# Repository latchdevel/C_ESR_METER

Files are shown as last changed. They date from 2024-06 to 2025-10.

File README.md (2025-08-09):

# C/ESR Meter

Capacitance "**C**" and equivalent series resistance "**ESR**" meter for electrolytic capacitors.

Hardware and software reimplementation of the Russian capacitance and ESR meter for electrolytic capacitors, posted on ["Pro-Radio" forum](https://pro-radio.online/measure/3288/) in 2006 by Gints Oleg (Гинц Олег) "GO". As he himself explains on [this website](http://www.rlc-esr.ru/index.php/ru/izmeritel-s-i-esr), he was inspired by a [previous project from 2004](Project_2004), about which there is not much information. Original Gints Oleg design is for sale as "DIY kit" on the ["Modul-X website."](http://modul-x.ru/radiokonstruktory/pribory/izmeritel-emkosti-i-posledovatelnogo-ekvivalentnogo-soprotivleniya-elektroliticheskikh-kondensatorov-c-esr-meter.htm)

In 2021 the user "**wegi1**" from the "Open Source Hardware Lab" forum publishes two projects that include the schematic and the PCB in "EasyEDA", [two dual Op-Amps](https://oshwlab.com/wegi1/oleg-c-esr-meter) and [one quad Op-Amp](https://oshwlab.com/wegi1/go-esr-c-meter)

In 2022 the Spanish Youtube channel "**RDT**" [Reparando de todo](https://www.youtube.com/watch?v=-c8M0YjmY34&list=PLTIVqAL9EezMypRtiyRqnYZjx48QQSnEL) make and share own SMD designs from original based. 

This device is not a precision instrument, but it is sufficient for the practice of radio amateurs and electronic repairs.

It is published under **Open Hardware** and **Open Source** licenses:
   - [CERN Open Hardware Licence Version 2 - Strongly Reciprocal](https://ohwr.org/cern_ohl_s_v2.txt)
   - [GNU General Public License v3.0](https://www.gnu.org/licenses/gpl-3.0.txt)
   - [Creative Commons Attribution-ShareAlike 4.0 International Public License](https://creativecommons.org/licenses/by-sa/4.0/legalcode.txt)

  

## Main features
- Measures ESR from 0.001Ω to 15.00Ω (approx), in two ranges.
- Measures capacitance from 1uF to 100,000uF (approx) very quickly.
- Its electronics are very simple, easy and cheap to build.
- Works below 100 mV on the capacitor under test, allowing in-circuit measurements.
- No capacitor pre-discharge required.
- Calibration by software.

## Principle of measurement
Measuring the capacitor's ESR is based on subjecting it to a pulse from a known current source and measuring the voltage drop across it.

The capacitor will be connected to a known constant current source "I=10mA" for a precise short period of time "10μS", when the capacitor is disconnected from the current source, the voltage across it will decrease as a function of "I*R". Knowing the current and voltage drop, the ESR can be calculated. It should be noted that this principle of measuring ESR is not new, it is simply not very common.

The capacitance is calculated by measuring the charging time of the capacitor between 30mV and 60mV with the same constant current of 10mA. In practice, the "33" gain output is used to compare it with 1V and 2V references.
This time is relatively small, approximately 3 microseconds per microfarad, but can be measured with sufficient precision for the most common capacitances of electrolytic capacitors.

## Reimplementation motivation
I learned about the GO meter thanks to "**RDT**" [Reparando de todo](https://www.youtube.com/watch?v=kafeiWaOLkQ) YouTube channel, which did a great job spreading the word about it.
And I immediately wanted to build one, but I also wanted to be able to modify it to my liking, and the fact that the code was written in assembler language posed a considerable difficulty. Furthermore, the language used was Microchip Assembler (MPASM), which is deprecated in favor of MPLAB XC8 PIC Assembler (pic-as). The last version that includes MPASM was [MPLAB X IDE v5.35 (2020)](https://ww1.microchip.com/downloads/en/DeviceDoc/MPASM%20to%20MPLAB%20XC8%20PIC%20Assembler%20Migration%20Guide%2050002973A.pdf).

Therefore, it made no sense to maintain or rewrite the code in assembler language, and I chose to reimplement it in a more comfortable language like C/C++. So it was no longer necessary to continue using a Microchip PIC, being able to use an Atmel AVR like those used by Arduino ecosystem, having numerous development boards and abundant open software libraries and tools.

This reimplementation of the software and hardware has been possible thanks to the fact that both the scheme and the source code were published, which could be compiled and executed in a simulator, which allowed obtaining a [basic flowchart of the GO meter operation](Russian_source/go_esr_flowchart.png).

Modifying the hardware allows you to add several improvements, some of them absolutely essential:

### VREF Voltage Reference 4 volts
An absolutely essential improvement is to add a 4V voltage reference to use as the VREF of the ADC, from which the 2v and 1v voltages, used as comparator inputs, would also be derived using simple voltage dividers.

Using Vcc (approximately 5V) as the ADC reference voltage is a very bad idea, since this voltage is highly variable and unstable, and it can never be reached at the output of the Op-Amps (if these do not have Rail-to-Rail output), losing measurement range.

The most accurate option would be to use a voltage reference of 4096mV, such as the LM4040 or MCP1541, which are inexpensive and even available in their manufacturers' sample programs, but the simplest thing would be to use another TL431 since it is easily configurable to 4v with only two resistors of 12kΩ and 20kΩ.

$V_o=2.5v*(1+\frac{R1}{R2})=2.5v*(1+\frac{12000Ω}{20000Ω})=2.5v*(1+0.6)=2.5v*1.6=4v$

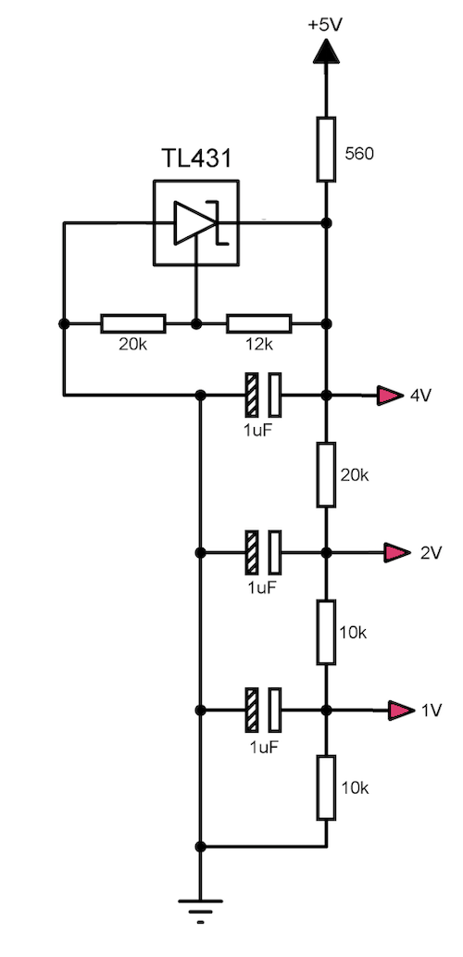
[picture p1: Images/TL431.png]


### AD620 Instrumentation amplifier
Another important improvement is replacing the four operational amplifiers (two TL072 dual Op-Amps or one TL084 quad Op-Amp) with a single AD620 instrumentation amplifier whose gain is configurable, being set by default to "33" and using one of the four switches on the CD4066B that was not used, the "330" gain can be selected.

The AD620 formula to calculate the resistances $R_g$ is:

$G=\frac{49.4kΩ}{R_g}+1$ 

$R_g=\frac{49.4kΩ}{G-1}$

Therefore:
 - For $G$ = 33, $R_g$ = 1543.75Ω approx **1.5kΩ** --> Single resistor (R1)
 - For $G$ = 330, $R_g$ = 150.15Ω approx **150Ω** --> 167Ω parallel circuit 1500Ω --> 143Ω (CD4066B $R_{on}$ @5v)<sup>1</sup> + 24Ω (R2)

 <sup>1</sup> CD4066B Quad bilateral analog switch $R_{on}$ @5v must be measured between pins 8 and 9.

VSS (-5V) negative voltage is still necessary, because it operates very close to zero voltage. Even modern Rail-to-Rail Op-Amps do not achieve an acceptable lineal result when operating so close to zero volts.
But now, the VSS level is not critical, it does not require lineal regulator or manual offset adjustment, since the AD620 has a reference terminal to set the potential that defines the zero output voltage, which can be connected directly to GND.

#### Original circuit with four generics Op-Amps 
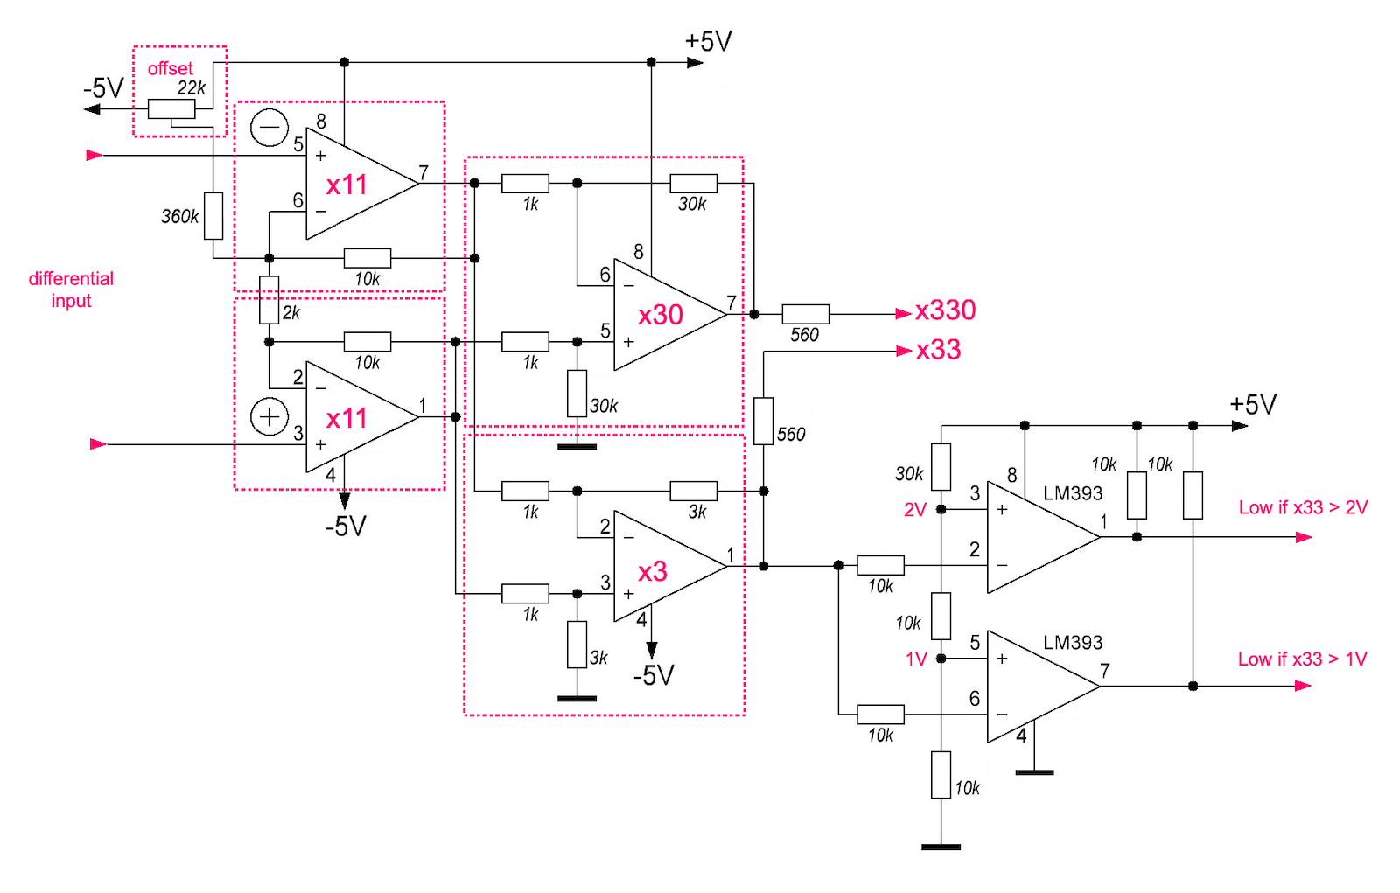
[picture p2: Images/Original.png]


#### New circuit with one instrumentation amplifier AD620
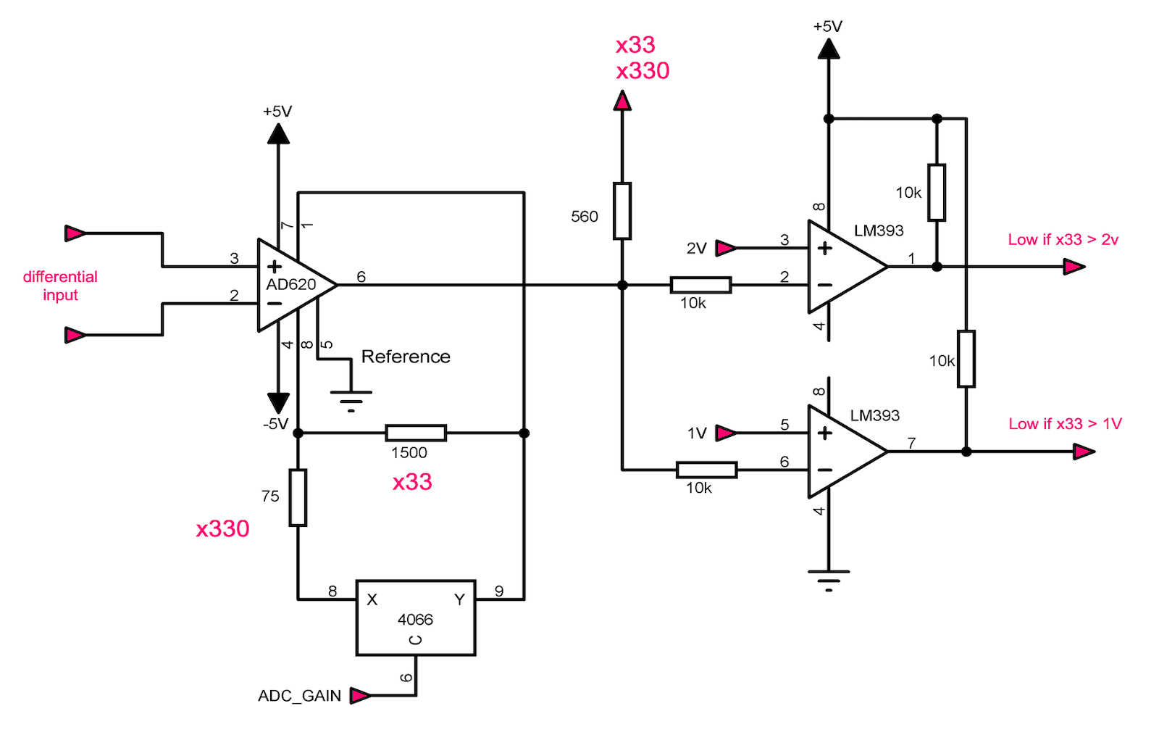
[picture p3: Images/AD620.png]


### MCU ATMega328p "Arduino Nano"
The microcontroller update is another substantial improvement, not only due to the increase in the capacity of program memory and RAM, since when using the Arduino framework there are low-cost development boards, which include all the necessary components and many accessories, from quartz crystal and capacitors, to voltage regulators and USB to Serial converters.
They also include a bootloader that makes it very easy to update firmware using a simple USB connection, without the need for an external hardware programmer.

* Change MCU from Microchip PIC16F87xA to Atmel ATMega328p (Arduino Nano (USB to Serial bridge included))
* Change programming language from old Microchip Assembler (MPASM) to modern C++ standard (avr-gcc c++11)
* Change float resolution from Microchip's 24-bit to IEEE-754 32-bit standard. [See the AN575 Python module for conversions.](https://github.com/latchdevel/AN575)
* Change the external ICSP hardware programmer to built-in USB bootloader for easy firmware update via USB connection.

| MCU | SRAM (bytes) | Program Memory (KB)| Data EEPROM (bytes) |
|:---|---:|---:|---:|
| PIC16F873A | 192 | 7 | 128 |
| PIC16F876A | 368 | 14 | 256 |
| ATMega328p | 2048 | 32 | 1024 |

### LCD I2C
Another improvement has been to change the connection interface of LCD display to I2C, adding a PCF8574 adapter, but this really simplifies its use and connection and provides greater flexibility when making modifications or expansions.
* Change from direct 4-bit HD44780 LCD interface to I2C interface via PCF8574 adapter.
* Change from raw display management to the comfortable ["LiquidCrystal I2C" Arduino library](https://www.arduino.cc/reference/en/libraries/liquidcrystal-i2c), that must be install via Arduino IDE library manager.

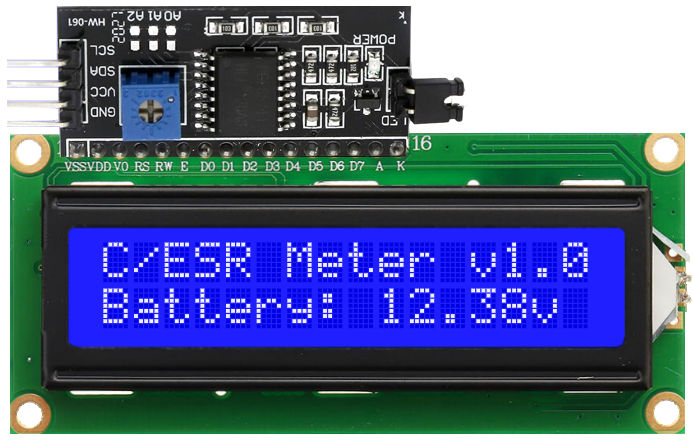
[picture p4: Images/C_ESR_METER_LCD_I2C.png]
LCD I2C interface


### Others hardware improvements:
* Add reverse polarity protection by MOSFET P-Channel transistor (Q3)
* Add power-on (Q4) and power-off (Q5) circuits 
* Add clamping diode protection (D6) to ADC
* Add buzzer with driver (Q6) and flyback diode protection

# Schematic

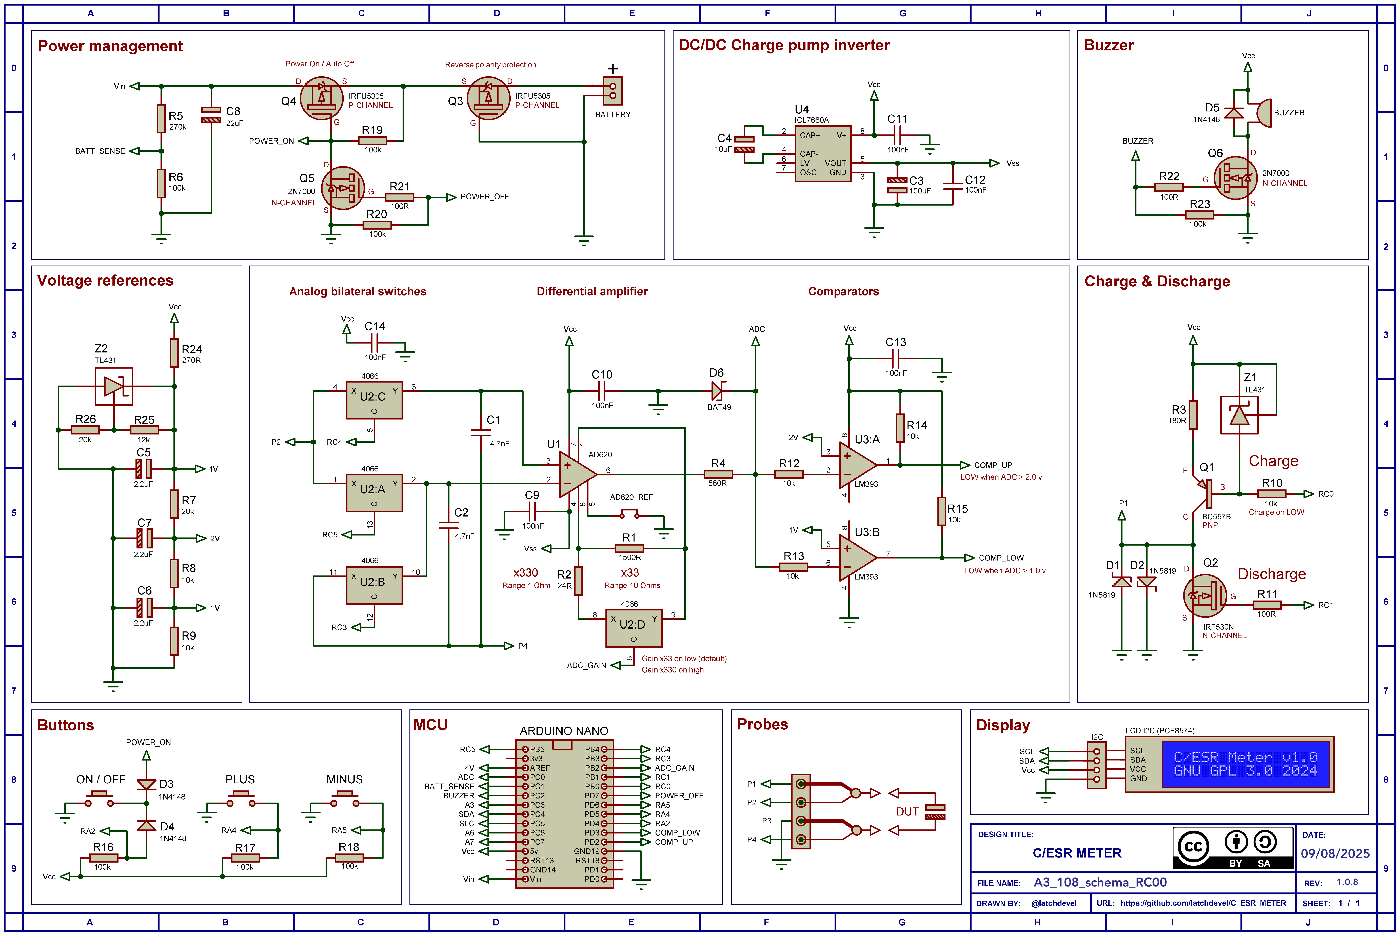
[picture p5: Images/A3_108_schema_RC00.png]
Schematic
[](Images/A3_108_schema_RC00.png)

# PCB
The proof-of-concept PCB is designed in just two layers with through-hole components so you can easily build it yourself, maintaining a small enough size for cheap manufacturing.

* Board size: 98mm x 78mm
* Distance between corner mounting holes: 90mm x 70mm
* Available LCD display (16x02) mounting holes: 75mm x 31mm

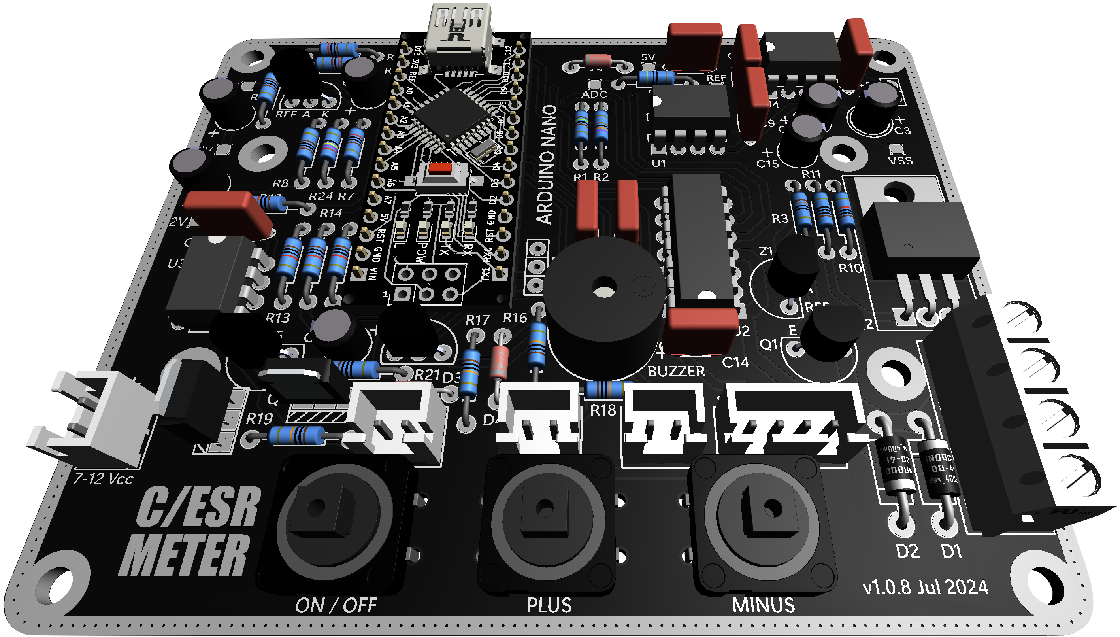
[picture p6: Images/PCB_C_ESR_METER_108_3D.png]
3D PCB


Gerber files for PCB manufacture are available [here](Gerber).

Bill of materials (BOM) for the complete assembly is available [here](BOM.md).

## Additional software improvements:
* Software power-off
* Software timed auto power-off with warning and clear
* Split “Test Mode” functions, (+) for capacitance “ticks” and (-) for raw ADC values in 1Ω and 10Ω ranges
* Calibration Menu displays values and makes changes on the fly
* Add configuration options for ESR "Set to Zero" in 1Ω and 10Ω ranges
* Add exponential moving average as IIR digital filter for Cx measures, with auto-hold and manual remeasure
* Low voltage battery protection
* Serial output debug info
* Serial output trace values (for graphic plot)

### Debug serial output example:

```
Booting C/ESR Meter v1.0
Battery: 12.38v

Hardware configuration:
-----------------------------
ADC_VREF_VALUE:       4.070
VBATT_FACTOR:         3.740
VBATT_MIN:            6.000v (max: 15.22v)

Hardware based parameters:
-----------------------------
M_ESR_1:              599.00
M_ESR_10:             79.00 (ESR limit: 12.95 ohms)
U330threshold:        950
M_Cx:                 51.00
add_Cx:               1000
ACD_MEASURES:         20
COMP_TIMEOUT:         80 (327 msecs) Cx max: 104085 uF

User calibration settings:
-----------------------------
ESR factor 1 ohm:     1.000
ESR factor 10 ohms:   1.000
Cx factor:            1.000
Cx counter:           1000
ESR set zero 1 ohm:   54
ESR set zero 10 ohms: 0

Auto power off warning timer: 120 secs (approx)
Auto power off timer:         180 secs (approx)
```

### Graphic plot serial output example:

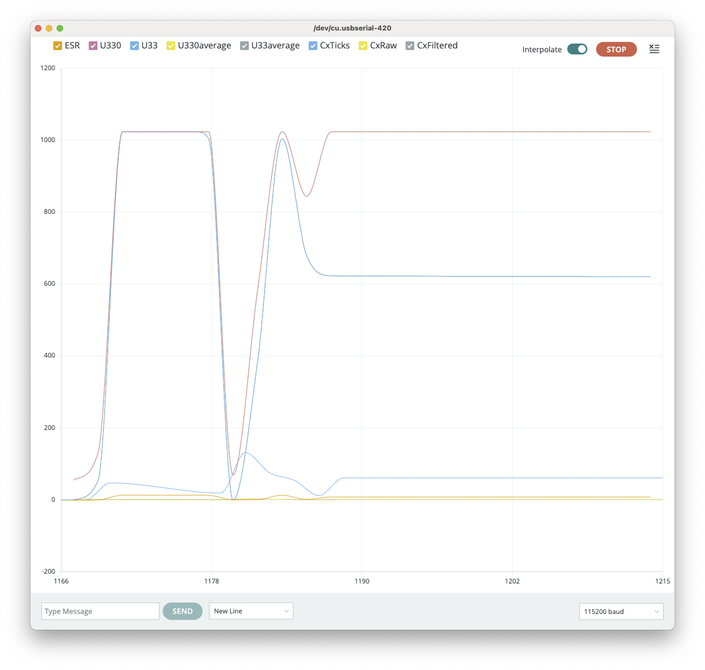
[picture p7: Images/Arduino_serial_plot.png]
Arduino serial plot


## Roadmap
- [X] [Schematic](Images/A3_108_schema_RC00.png)
- [X] [Gerber PCB files](Gerber)
- [X] [BOM](BOM.md)
- [X] [Arduino C++ source code](C_ESR_METER.ino)
- [X] [PIC ASM source code](Russian_source/go_esr_1.17_2023_UTF8.asm)
- [X] [PIC ASM flowchart](Russian_source/go_esr_flowchart.png)
- [X] [PIC AN575 float format](https://github.com/latchdevel/AN575)
- [ ] Enclosure's 3D model
- [ ] Build guide
- [ ] Calibration manual
- [ ] User manual

# Remembering Bob Pease "RAP"
[Robert Allen Pease "RAP"](https://en.wikipedia.org/wiki/Bob_Pease) (August 22, 1940 - June 18, 2011) 

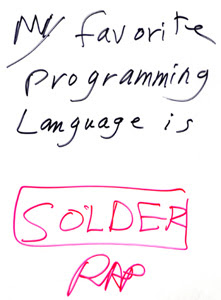
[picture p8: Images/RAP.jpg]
My favorite programming language is solder
[](https://en.wikipedia.org/wiki/Bob_Pease)

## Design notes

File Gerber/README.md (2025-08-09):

# Gerber files for "C/ESR Meter"

**Board revision v1.0.8 (Jul 2024)**

```
File List
---------
Top Copper              : C_ESR_METER_1.0.8_R11 - CADCAM Top Copper.GBR
Bottom Copper           : C_ESR_METER_1.0.8_R11 - CADCAM Bottom Copper.GBR
Top Silk Screen         : C_ESR_METER_1.0.8_R11 - CADCAM Top Silk Screen.GBR
Bottom Silk Screen      : C_ESR_METER_1.0.8_R11 - CADCAM Bottom Silk Screen.GBR
Top Solder Resist       : C_ESR_METER_1.0.8_R11 - CADCAM Top Solder Resist.GBR
Bottom Solder Resist    : C_ESR_METER_1.0.8_R11 - CADCAM Bottom Solder Resist.GBR
Drill, Unplated, 1-16   : C_ESR_METER_1.0.8_R11 - CADCAM Drill TOP-BOT NonPlated.GBR
Drill, Plated, 1-16     : C_ESR_METER_1.0.8_R11 - CADCAM Drill TOP-BOT Plated.GBR
Drill, Filled, 1-16     : C_ESR_METER_1.0.8_R11 - CADCAM Drill TOP-BOT Filled and Plated.GBR
Netlist                 : C_ESR_METER_1.0.8_R11 - CADCAM Netlist.IPC
```

## Top view

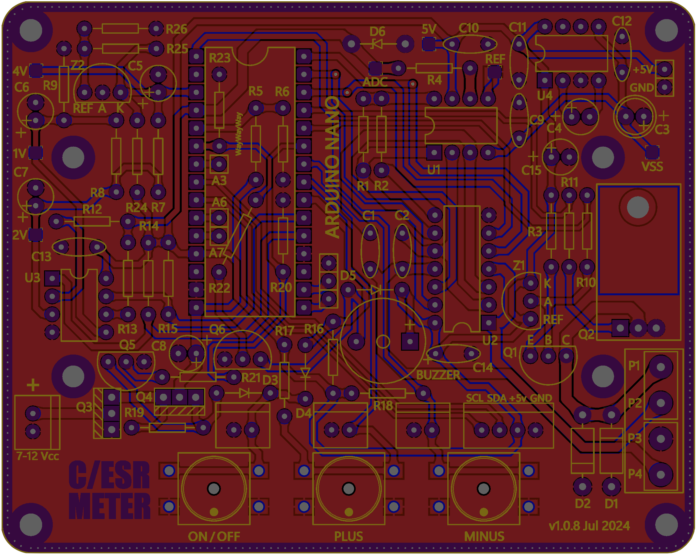
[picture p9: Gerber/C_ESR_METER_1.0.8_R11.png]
C_ESR_METER_1.0.8_R11


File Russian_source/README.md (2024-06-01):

# Измеритель С и ESR.

Source: https://www.rlc-esr.ru/index.php/ru/izmeritel-s-i-esr

I have long wanted to make a device for checking electrolytes that, along with ESR, would also measure capacity. Everything I came across on the Internet on this topic was somehow unsatisfactory. After trying out some ideas, I settled on the option of determining ESR by measuring the magnitude of the voltage drop (step) when the capacitor is DISCONNECTED from the current source. Capacity is determined in the traditional way - measuring the charging time with a stable current (10 mA)
 
The device is designed to determine the health of electrolytic capacitors by measuring capacitance (C) and equivalent series resistance (ESR). The device is not a precision instrument, but its accuracy is sufficient for amateur radio practice and repair of radio-electronic devices. The voltage across the element under test is about 100 mV, which allows for in-circuit measurements. Protection of input circuits is traditional - two back-to-back diodes and is ineffective. It is better to solve this problem mechanically - with the help of special probes, which in the normal state are closed to each other through a resistance of about 5 Ohms, and when the probe is pressed, this circuit would open.

**Measurement limits:**
 - C: 1 - 150000 µF
 - ESR: 0 - 10 Ohm

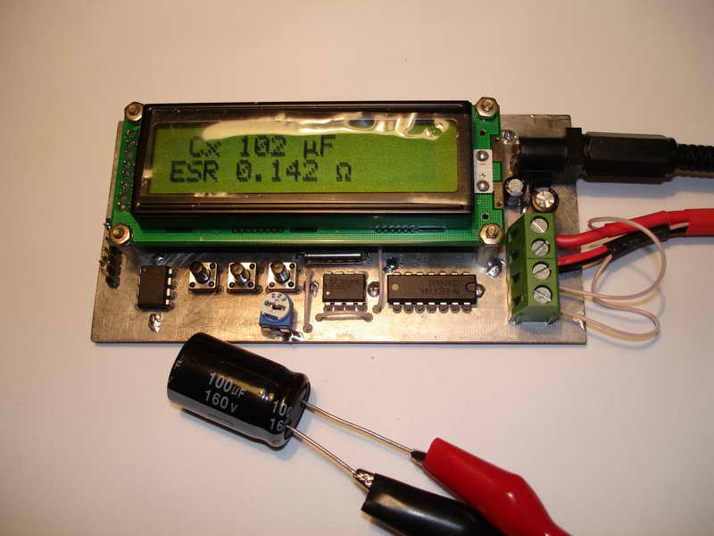
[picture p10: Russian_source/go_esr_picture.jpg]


## Principle of measurement

The device uses the principle of measuring ESR - almost constant current. I’ll try to explain in more detail, let’s imagine a SIMPLIFIED equivalent equivalent circuit of an electric capacitor - the actual ideal capacitor C and the resistance R connected in series with it. Let's connect this circuit to a current source I. At the initial moment, the voltage on this circuit will be equal to U=I*R, then the voltage will increase linearly due to the charge of the capacitor U=I*R+I*t/C (t-time). When the capacitor is disconnected from the current source, the voltage across it will decrease by the amount I*R. This value is measured by the device. Knowing the current and the magnitude of the voltage drop, we obtain ESR.

In practice, it looks like this - the capacitor is first discharged, a 10 mA current source is turned on, both inputs of the measuring amplifier are connected to Cx, a delay of about 3.6 μs is made to eliminate the influence of ringing in the wires. Simultaneously via DD2.3 keys || DD2.4 charges capacitor C1, which actually remembers the highest voltage that was on Cx. The next step is to open the keys DD2.3 || DD2.4 and the current source is turned off. The inverting input of the remote control remains connected to Cx, on which, after turning off the current, the voltage drops by 10 mA * ESR. That's actually all - then you can easily measure the voltage at the output of the remote control - there are two channels, one with KU = 330 for the limit of 1 Ohm and KU = 33 for 10 Ohms. It turns out that these same analog circuits are used to measure capacitance.

It should be noted that this principle of ESR measurement is not new, it just does not occur very often. Here is the most similar design, only here the measurement is carried out when the current is turned on. A similar principle was used in the [“Digital ESR Meter” by S. Biryukova, Circuit Engineering 2-3 2006.](../Project_2004/)

## Schematic

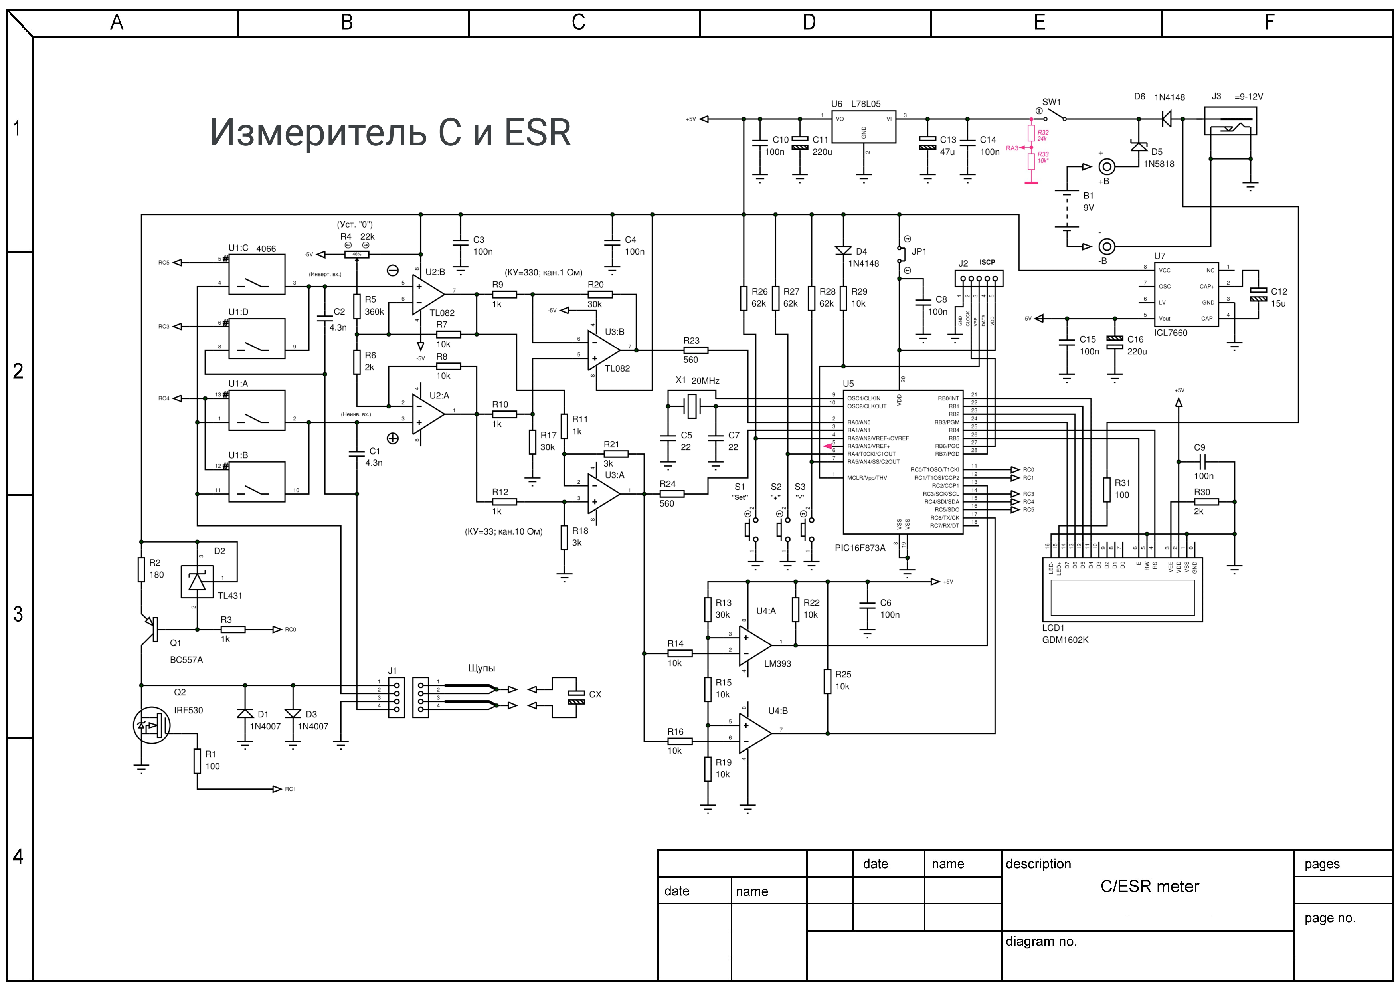
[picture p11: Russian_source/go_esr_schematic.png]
Schematic


## BOM

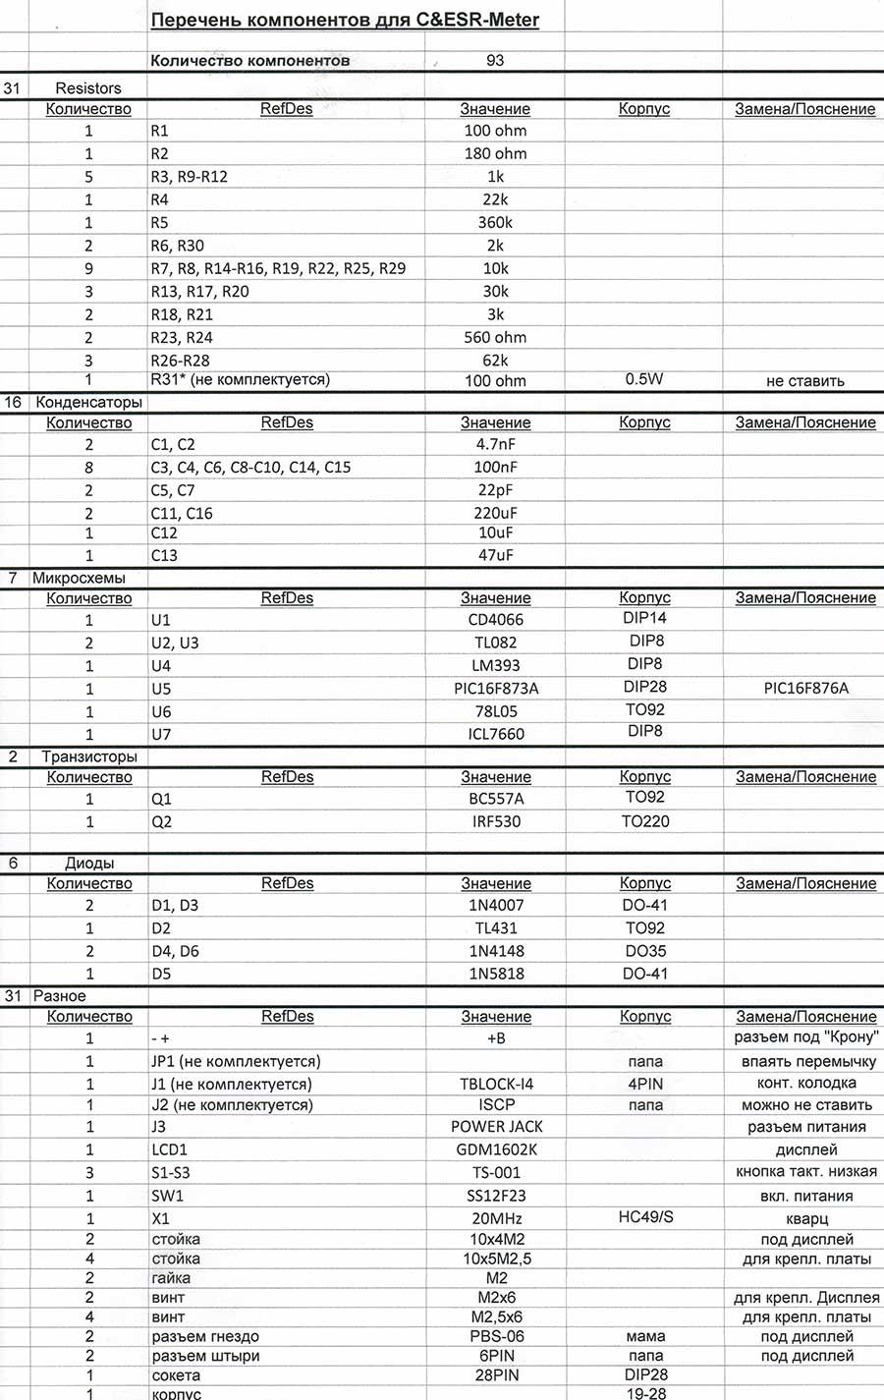
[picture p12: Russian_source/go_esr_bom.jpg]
BOM


## Setup and management

First turn on - check for the presence of +5V after 78L05 and -5V (4.7V) at the DA4 output. By selecting R31 we achieve normal contrast on the indicator.
Turning on the device while pressing the Set button puts it into the mode for setting correction factors. There are only three of them - for 1 Ohm, 10 Ohm channels and for capacitance. Changing coefficients using the + and - buttons, writing to EEPROM and searching through the same Set button.
 
There is also a debugging mode - in this mode the measured values are displayed on the indicator without processing - for capacitance - the state of the timer (approximately 15 counts per 1 µF) and both ESR measurement channels (1 ADC step = 5V/1024). Switch to debugging mode - while pressing the "+" button.
 
Zero setting. To do this, we close the input, press and hold the “+” button and, using R4, achieve minimum readings (but not zero!) simultaneously on both channels. Without releasing the "+" button, press Set - the indicator will display a message about saving U0 in EEPROM. Next, we measure standard resistances of 1 Ohm (or less), 10 Ohms and capacitance (which you trust), and determine correction factors. We turn off the device, turn it on while pressing the Set button and set the coefficients according to the measurement results.
Indication.

The measured values are displayed in digital format on a two-line LCD. The top line displays the capacitance, and the bottom line displays the ESR of the capacitor.

The inscription "`Cx ----`" is displayed in the following cases:

   - When measuring capacitance, a timeout is triggered, i.e. During the allotted measurement time, the device did not wait for both comparators to switch. This happens when measuring resistors, shorted probes, or when the measured capacitance is >150,000 µF, etc.

   - When the voltage measured at the DA2.2 output exceeds 0x300 (this is the ADC reading in hexadecimal code), the capacitance measurement procedure is not performed and Cx ---- is also displayed on the indicator. With open probes (or R>10 Ohm) this is how it should be.

The "`>`" sign in the ESR line appears when the voltage at the DA2.2 output exceeds 0x300 (in ADC units).

## Parts and probes

LCD module based on the HD44780 controller with 16 characters, 2 lines. There are versions with “confused” legs 1 and 2 - ground and power. The correct marking must be found in the documentation for the indicator. Other indicators will require program changes. We will replace the microcontroller with a PIC16F873 with a clock frequency of 20 MHz. We will replace the IRF530 transistor with IRF520, IRF540, IRLZ44n.

Remote probes are connected using a four-wire circuit to reduce the influence of wire resistance on the measurement result. The wires going to ground and transistor VT2 need to be thicker.

The device is being discussed on the forum: https://www.pro-radio.ru/measure/3288/

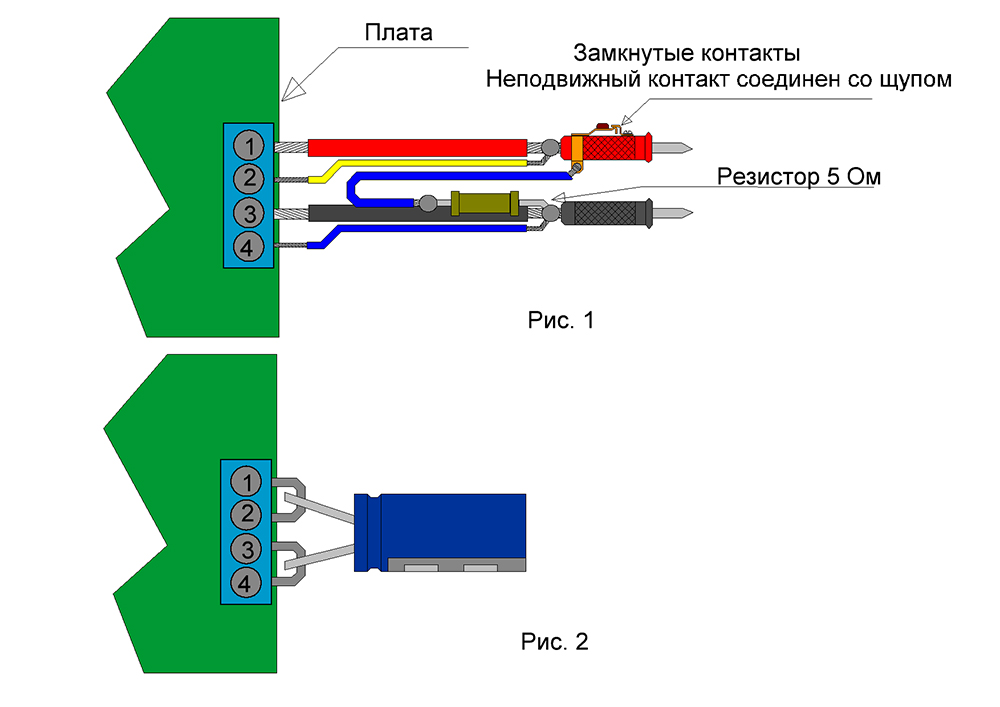
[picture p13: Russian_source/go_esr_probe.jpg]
Probe


## Flowchart

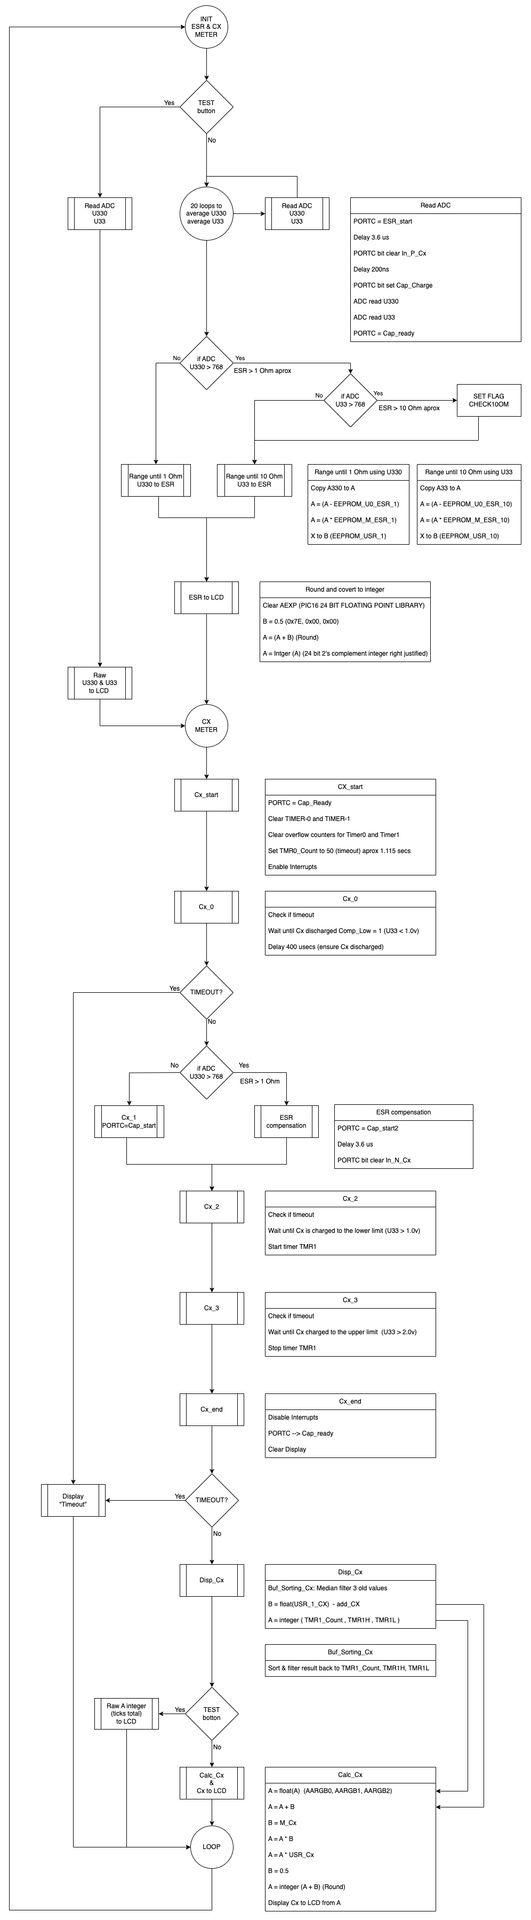
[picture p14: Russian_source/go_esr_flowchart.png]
Flowchart


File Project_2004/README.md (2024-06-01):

# PIC Based Low Cost ESR meter (2004)

## Schematics and images:
   - https://web.archive.org/web/20070105002912/http://saint.419.removed.us/esrtest.html
   - https://www.electronica-pt.com/circuitos/en/pics/esr-meter

## ASM source code: 
   - https://electronics-diy.com/schematics/856/esrprg.html
   - https://www.electronica-pt.com/circuitos/zip/esr-meter.txt.zip

## Project Specifications
- **PIC**: PIC16F876A
- **Processor Frequency**: 3.58MHz
- **Display Type**: 16 Character x 2

ESR Meter can read equivalent serie resistor in a capacitor inserted in circuit.

**Use**: The capacitance value of the device under test (DUT) is measured finding time taken to charge it to a particular voltage.

The ESR of DUT is measured subjecting it to a knowned current pulse and read voltage across it.

**Calibration**: Take a good capacitor, around 100 or 1000 microfarads, and connect a small resistor, 10 or 5 ohms, in series with it. Connect to the meter and adjust that pot until the meter reads the resistance of that resistor. Repeat with other capacitors and resistors as a check on your calibration.

**Limitations**: Capacitors smaller than about 10 microfarads cannot be measured with ESR. Capacitance down to 10 picofarads may be measured, however devices with appreciable leakage cannot be measured at all for capacitance.

This is a design for a capacitance and ESR meter using a PIC16F876.

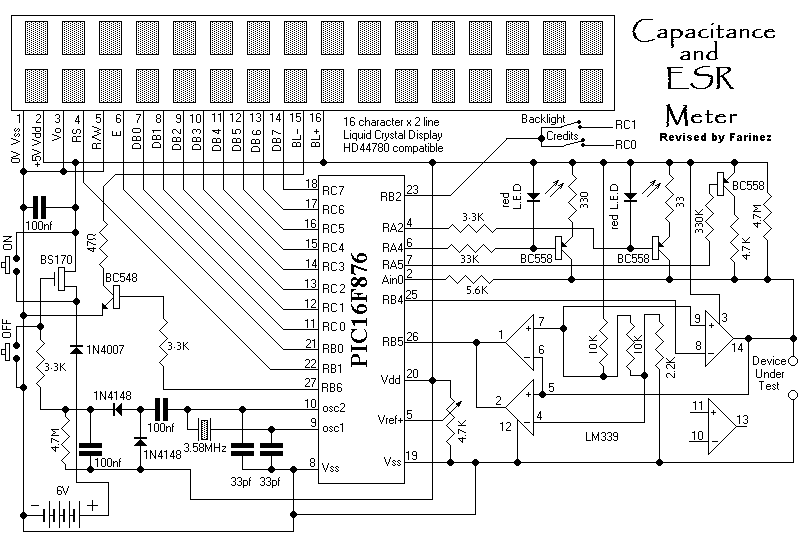
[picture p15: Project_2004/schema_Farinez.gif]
Schema


The track pattern

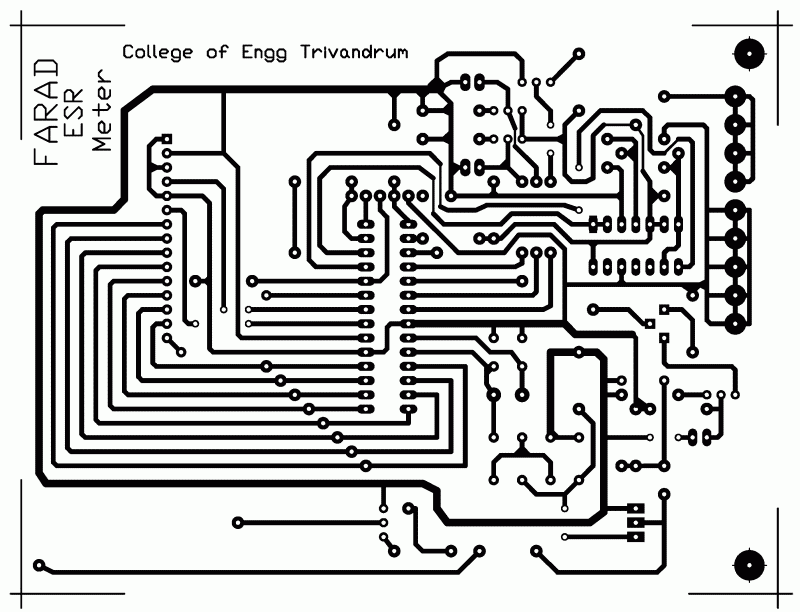
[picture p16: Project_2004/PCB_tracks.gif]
Tracks


The PCB overlay

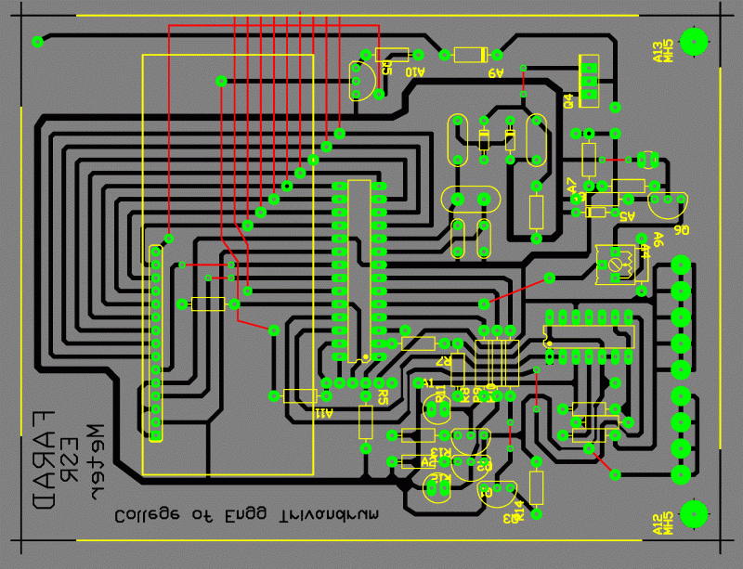
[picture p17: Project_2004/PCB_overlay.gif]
Overlay


The partly populated circuit board

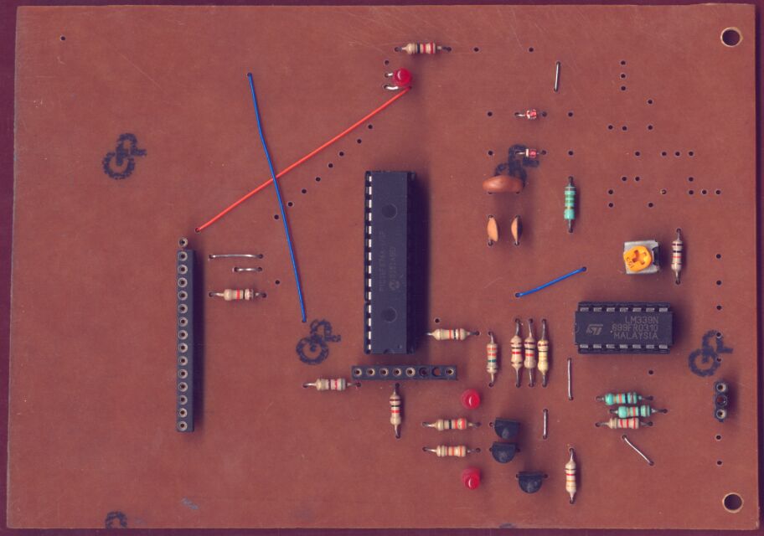
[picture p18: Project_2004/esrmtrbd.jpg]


## Working:

The capacitance of the Device Under Test (DUT) is measured by finding the time taken to charge it to a particular voltage.

The Equivalent Series Resistance (ESR) of the DUT is measured by subjecting it to a pulse of known current, and finding the voltage developed across it.

## Capacitance Measurement:
There are two ranges: A resistance of 4.7 Megohms is directly connected from the "hot" terminal of the DUT to the positive supply voltage. A resistance of 4.7 Kilohms can be connected to the positive rail by switching a transistor on.
Initially, the measurement is attempted with the 4.7K resistor. The time taken for the DUT to charge to a particular voltage is measured. If the result is too small, the resistor is switched off and the measurement is attempted again with the 4.7M resistor. Thus the two ranges differ by a factor of 1000.

## ESR Measurement:
There are two ranges: First, a constant current source of about 5 mA is switched on and the voltage across the DUT is measured. If the reading is too low, the voltage reading is repeated with a current of 50 mA. Thus the two ranges differ by a factor of 10.

The DUT is discharged using one comparator in the LM339 as a switch. Adequate time has to be allowed in between readings in order to discharge the DUT fully.

The measurement of ESR is only valid for capacitors larger than about 10 microfarads or so. This is because smaller capacitors charge up from the pulse of current used to test them.

## Principle of Measurement: Capacitance

The DUT is discharged to get rid of any charge it might have accumulated during the previous measurement cycle.

It is then connected to the positive rail through a 4.7 Kilohm resistor. Two comparators in the LM339 monitor the voltage on the DUT as it charges up.

The two comparators are connected as a window discriminator. The communed output of these two comparators will be high when the input is above the lower threshold of around 10% supply voltage and go low when it crosses the higher threshold of around 50% supply voltage. The lower threshold has been used in order to obviate any errors due to the DUT not being discharged completely.

The width of the pulse of the window discriminator is proportional to the capacitance of the DUT. This is measured in a loop. Calibration is by adjusting the delays inside this loop, by padding it with goto's and nop's.

If the result points to a small value of capacitance, the measurement is attempted again with just the 4.7 Megohm resistor. This time, the pulse width is measured by a separate loop so that the range can be separately calibrated. This loop has the provision of compensating for the fixed capacitance of the circuit in parallel with the DUT (zeroing).

## Principle of Measurement: Equivalent Series Resistance

Again, the DUT is discharged to get rid of any charge it might have accumulated during the previous measurement cycle.

It is then subjected to a short pulse of current - just long enough for the ADC inside the PIC to acquire a reading. Since the pulse is short, the capacitive part of the DUT is assumed to be uncharged. The voltage drop across the DUT is then contributed by its ESR alone. Thus the voltage read from the ADC is proportional to the ESR, and may be displayed as such.

This measurement is calibrated by adjusting the reference voltage applied to the internal ADC of the PIC.

## Limitations

Capacitors smaller than about 10 microfarads cannot be measured for ESR. Capacitance down to 10 picofarads may be measured, however. Devices with appreciable leakage cannot be measured at all for capacitance.

## Bugs

The instrument hangs for a long time if a large capacitor is connected while it is measuring in the low capacitance range.

## Enhancements

A fast Sample-and-Hold Amplifier could be used ahead of the PIC analogue input in order to extend the measurement range of ESR to devices of lower capacitance.

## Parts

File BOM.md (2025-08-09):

# Bill Of Materials for "C/ESR Meter"

**Board revision v1.0.8 (Jul 2024)**

## Resistors

| Quantity | References (1% 1/4 watt 400mil) | Value | Comments |
|:---:|:---|---:|:---|
| 1 | R1 | 1500R | AD620 gain "33" (default 10Ω range). Theoretical 1543.75Ω. If R1=1500R --> G=31.9
| 1 | R2 | 24R | AD620 gain "330", (1Ω range). It depends on $R_{on}$ between pins 8 and 9 of 4066 at 5v which should be measured. Target 167Ω adding R2 and (4066 8/9 $R_{on} @5v$)
| 1 | R3 | 180R | Z1 current limiter to charge DUT to 10mA. $I_o = \frac{V_{ref} - V_{be}}{ R_s } = \frac{2.5v - 0.7v}{ 180Ω } = \frac{1.8v}{ 180Ω } = 0.01A = 10mA$ 
| 1 | R4 | 560R | ADC current limiter, any approximate value will work fine
| 1 | R5 | 270k | Together with R6 they form a voltage divider to measure the battery level. Their ratio must be defined in the source code: `#define VBATT_FACTOR 3.7 // = 1+(R5/R6) = 1+(270k/100k) = 1+(2.7) = 3.7`
| 1 | R6 | 100k | R6 together with R5 form a voltage divider, see R5
| 2 | R7, R26 | 20k | They are part of the voltage dividers for voltage references
| 1 | R25 | 12k | It is part of the voltage dividers for voltage references.
| 2 | R8, R9 | 10k | They are part of the voltage dividers for voltage references
| 5 | R10, R12, R13, R14, R15 | 10k | Pull-up and current limiters, any approximate value will work fine
| 6 | R16, R17, R18, R19, R20, R23 | 100k | Pull-up and pul-down resistors, any approximate value will work fine
| 3 | R11, R21, R22 | 100R | MOSFET current limiters, any approximate value will work fine
| 1 | R24 | 270R | Z2 current limiter, any approximate value will work fine.

## Capacitors

| Quantity | References | Value | Comments |
|:---:|:---|---:|:---|
| 2 | C1, C2 | 4.7nF | (200mil) Non-polarized polyester capacitors
| 1 | C3 | 100uF | (100mil) Negative voltage filter, polarized electrolytic capacitor (16v) from 100uF it will be fine
| 1 | C4 | 10uF | (100mil) Charge-Pump capacitor, polarized electrolytic capacitor (16v)
| 1 | C8 | 22uF | (100mil) $V_{in}$ capacitor, polarized electrolytic capacitor (50v)
| 3 | C5, C6, C7 | 2.2uF | (100mil) Voltage dividers load capacitance are required, from 1uF to 10uF, polarized electrolytic capacitors (16v)
| 6 | C9, C10, C11, C12, C13, C14 | 100nF | (200mil) Noise filters, non-polarized ceramic capacitors should be close to the device (within 5 mm of the pin)
| 1 | C15 | 100uF | (100mil) Optional +5v output capacitor, polarized electrolytic capacitor (16v) from 100uF it will be fine

## Diodes

| Quantity | References | Value | Comments |
|:---:|:---|---:|:---|
| 2 | D1, D2 | 1n5819 | (400mil) Low drop power Schottky rectifier diode
| 3 | D3, D4, D5 | 1n4148 | (300mil) General purpose small signal high-speed switching diode
| 1 | D6 | BAT49 | (300mil) Very low turn-on voltage small signal Schottky diode (Vf=180mV)

## Transistors

| Quantity | References | Value | Comments |
|:---:|:---|---:|:---|
| 1 | Q1 | BC557B | TO-92  BJT PNP like as BC557A, BC558, 2N3609 (EBC pinout warning), etc.
| 1 | Q2 |  IRF530N | TO-220 MOSFET N-Channel like as IRF520, IRF540, IRLZ44N or similar
| 2 | Q3, Q4 | IRFU5305 | TO-251 MOSFET P-Channel low $RDS_{on}$
| 2 | Q5, Q6 | 2N7000 | TO-92  MOSFET N-Channel general purpose

## Integrated circuits

| Quantity | References | Value | Comments |
|:---:|:---|---:|:---|
| 2 | Z1, Z2 | TL431 | TO-92  Adjustable precision voltage reference ($V_{ref}=2.5v$)
| 1 | U1 | AD620 | DIP-8  Low cost, high accuracy instrumentation amplifier (INA129 gain equation compatible)
| 1 | U2 |  CD4066B | DIP-14 Quad bilateral analog switch, CMOS device type “4066” compatible such as HEF4066, HCF4066, 74HC4066, M74HC4066, MC14066, MAX4066, etc. $R_{on} @5v$ must be measured between pins 8 and 9 to add to R2
| 1 | U3 | LM393 | DIP-8  Dual independent low offset voltage precision comparators
| 1 | U4 | ICL7660A | DIP-8  Switched-Capacitor voltage converter (Intersil/Renesas)

## Miscellaneous

| Quantity | References | Comments |
|:---:|:---|:---|
| 1 | LCD display 16x02 (5v) HD44780 or similar |
| 1 | LCD I2C adapter (PCF8574) |
| 1 | Active buzzer 5v (12 mm) (7.6mm pitch) |
| 3 | Button SPST (normal open) 12mm | 
| 4 | Header connector 2-Pin JST male (2.54mm pitch) | Optional
| 1 | Header connector 4-Pin JST male (2.54mm pitch) | Optional
| 1 | Terminal block connector 4-Pin (5mm pitch) | Optional
| 1 | Enclosure Bahar BDC30001-A | Optional

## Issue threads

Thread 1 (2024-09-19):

Calibration method for ESR meter

lpkf2018, 2024-09-19:
Hello, I am very interested in your ESR meter. I plan to make one myself, but I found that there is no calibration method for the meter. Could you please publish a brief document on ESR meter calibration? I really need it. thank you!

latchdevel, 2024-09-20:
Hi, I'm glad you're interested.
I'm sure you won't regret making one, it works great.

You have to keep in mind that there are two stages, first you need to set the "hardware-based parameters" after assembly. This is extremely simple, only two resistors and a reference capacitor are needed.

To obtain the ESR parameters, **pressing the "minus button"** shows the RAW values   of the ADC, both for the 1 ohm range and for the 10 ohm range.
- First, open the probes, both readings should saturate the ADC and show 1023 and 1023. If not, there is a problem.
- Second, short the probes, a low value will be displayed for the 1 ohm range, for example 29, and zero for the 10 ohm range, and without releasing the minus button, press the menu button to set this ADC value as zero ERS.
- Third, place a 1 Ohm reference resistor as DUT, and note the value for 1 Ohm range, for example 570. This is the approximate value that will be set as the value of `M_ESR_1` in the code.
- Fourth, place a 10 ohm reference resistor as the DUT, and note the value for the 10 ohm range, for example 890. This value divided by 10 will be set as the value of `M_ESR_10` in the code.

To obtain the Cx parameters, **pressing the "plus button**" shows the RAW value of the Timer1 tick counter.
- Place the reference capacitor, for example 100 uF, and note the counter value. This value divided by the capacitor capacitance in uF is what should be set as the value of  `M_Cx` in the code.
- Cx fine tuning is done by varying the value of `add_Cx` in the code.

You can then perform a fine calibration adjustment which is stored in the EEPROM and can be modified from the user menu, accessed by holding the menu button at power up.

And the ESR zeroing is always available and easily accessible, since it depends a lot on the connected probes.

But you are right, it is necessary to publish a complete document on this topic.
I have just made a small update to the circuit, it may be the right time to publish the rest of the documentation.

I hope to be able to do it in the next few weeks.
Regards.

mockendon, 2025-04-13:
Many thanks for updating this project and the excellent PCB design. Please may I ask about troubleshooting in relation to calibration.  I have calibrated with the 1R, 10R and known Capacitor using the calibration menu on the meter (no values changed in the code).  The test points on the PCB all measure correctly (within 0.1V).  Capacitance measures reliably but I always get an ESR of 0.000.  Is it mandatory to set the values in the code or have I made some mistake in my assembly?  My scope shows 40mV ptp pulses of 40KHz on the meter outputs.

latchdevel, 2025-04-14:
Hi @mockendon,

I'm glad you decided to try it. You won't regret it; it works very well and is very easy to assemble.

First of all, just a couple of initial considerations.

- The 'REF to GND jumper' on the bottom layer must be soldered.

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

- The test probe connections must be in 'operational conditions', meaning there must be continuity between P1 and P2, as well as between P3 and P4. This setup is referred to as the 'OPEN' state.

Setting the values   in the code is mandatory, as it is necessary to adjust the instrument to the actual values   of the components used, and this adjustment is done by software.
But don't worry, there are only three important parameters, and they are very easy to calculate.
 - **M_ESR_1**
 - **M_ESR_10**
 - **M_Cx**

All the components are common and easy to obtain; just be careful with two of them:
 - The **AD620** instrumentation op amp, which must be "original"; there are many copies that don't work well. INA129 or even INA128 could be used, although I haven't tested them.

 - The **4066** must be selected carefully, and above all, the resistance in "on" of the third switch must be measured when operating at 5 V, pins 8 and 9. This resistance must be added to **R2** to obtain a total as close to **167 Ω** as possible.

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

Here are some that I have tested:
```
  - TI CD4066B Original    143 Ω -> Very good and easy to obtain, but make sure it's "original".
  - Philips HEF4066B        87 Ω -> Very good, but hard to get.
  - ST HCF4066BE           160 Ω -> Good.
  - TI CD4066B Aliexpress  204 Ω -> Bad.
  - Toshiba 74HC4066A       55 Ω -> Not usable because they have a certain resistance in "off" that alters the range of 10 Ω.
  - Philips 74HC4066N       30 Ω -> Not usable because they have a certain resistance in "off" that alters the range of 10 Ω.
```

Setting the **M_ESR_1**, **M_ESR_10**, and **M_Cx** values   is part of the instrument's construction. They must be fine-tuned until precise values   are obtained for their corresponding references. They are directly related to the components used, so once set, they should not be changed.

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

In normal use, the "ESR set zero" must be updated for each probe used, and the "calibration menu" is always available to correct any deviations.

I hope this helps.
Let me know how you're doing, and if you need anything, I'd be happy to help

Best regards.

mockendon, 2025-04-14:
Fantastic, thank you so much for this extra detail - I can see you are hard at work on the manual!  **The 'ref' jumper was the key,**  I now have plausible M_ESR_1, M_ESR_10 & M_Cx values and the ESR values are also realistic.  **I have a working ESR meter** - this is a significant contribution to the Open Hardware and Software community.  You deserve my thanks and that of many yet to come for your excellent work here.

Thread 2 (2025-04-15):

Suggested Feature request - Good or bad cap based on LCM3 predicted values

mockendon, 2025-04-15:
It would be super convenient if the meter displayed whether the capacitor was likely in specification for its measured capacitance.

The Table of Pudics István & Piri Dániel 2010 gives a suggested logarithmic scale for this (attached).

If we take the 63-100V line and find the equation of that line we can calculate that the upper limit for ESR is:

R = (C/81.303) ^(1/-1.085)

Where R is Ohms and C is in uF

Could we calculate this value on the fly and display a symbol to show 'good' or 'bad' as a guide?

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

mockendon, 2025-04-15:
So I have implemented this (poorly, I can only apologise for adding my terrible hack to your elegant code) as a proof of concept by adding these lines to these sections.  It displays either and 'OK' or an 'X' symbol after the ESR measurement.  Modified .ino attached.

[C_ESR_METER_modified.zip](https://github.com/user-attachments/files/19765841/C_ESR_METER_modified.zip)

```
#define OK    (byte)5                     // LCD custom char for OK character
#define BAD   (byte)6                     // LCD custom char for Bad character

 // OK character
byte ok[8] = {
  0b00000100,0b00001010,0b00001010,0b00000100,0b00001000,0b00001010,0b00001100,0b00001010
};

// Bad character
byte bad[8] = {
  0b00000000,0b00010001,0b00001010,0b00000100,0b00001010,0b00010001,0b00000000,0b00000000
};

// --------------------- Global vars ---------------------
bool CapOK                = false;        // True if ESR less than predicted

  // Init LCD
  lcd.init();
  lcd.createChar(SKIP,  skip);    // Skip address 0x00
  lcd.createChar(OMEGA, omega);   // "Ω" Omega      \1
  lcd.createChar(MU,    mu);      // "µ" Mu (micro) \2
  lcd.createChar(BELL,  bell);    // bell           \3
  lcd.createChar(LOCK,  lock);    // lock           \4
  lcd.createChar(OK,  ok);        // ok             \5
  lcd.createChar(BAD,  bad);      // bad            \6

// Get Cx measure
// Receives ESR measure to passthrough it to Cx meter function
// Returns Cx (µF) or any negative value when timeout

float predESR = pow((Cx/81.303),1 / -1.085);
if (predESR > esr){CapOK = true;}else{CapOK = false;}

// -------------------- Display Functions ------------------

// Display ESR (Ω) Ohms normal "ESR run mode"

  // Display good or bad symbol
  lcd.setCursor(15,1);              // Display to last position LCD second line
  if(CapOK == true){
    lcd.print(F("\5 ")); // "OK"
  }else{
    lcd.print(F("\6 ")); // "X"
  }

```

latchdevel, 2025-04-18:
Hi,

The approach you describe is very good, although it's difficult to determine the correct values.

The ESR of capacitors is greatly influenced by temperature and measurement frequency, and only the manufacturer can specify the correct value.

Some manufacturers provide detailed information, so much so that even for the same capacitor with the same capacitance and voltage, the ESR varies depending on its size.
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

**If it works for you, great!**; this is the advantage of open source.

Although I would recommend a more appropriate use of Git and GitHub to facilitate sharing your proposals: clone the repository, create a branch, commit your changes, and make a pull request if you want.

In any case, I'll think about this for a few days to find the best way to integrate this feature.

Best regards.

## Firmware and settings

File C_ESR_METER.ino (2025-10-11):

/*
  C/ESR Meter

  Reimplementation of the Russian capacitance and ESR meter for electrolytic capacitors, 
  posted on "Pro-Radio" forum in 2006 by Gints Oleg (Гинц Олег) "GO".
  
  See https://github.com/latchdevel/C_ESR_METER

  Copyright (c) 2023-2024 Jorge Rivera. All right reserved.
  License GNU General Public License v3.0.
*/

#define MESSAGE "C/ESR Meter" // 11 chars max
#define VERSION "1.0"         //  3 chars max

#if !defined(__AVR_ATmega328P__)
  #error "Required any Arduino using Atmel ATMega328p MCU"
#endif

#if F_CPU != 16000000L
  #error "Required 16Mhz clock"
#endif

#include <EEPROM.h>             // Arduino EEPROM library included (v2.0)
                                // https://docs.arduino.cc/learn/built-in-libraries/eeprom

#include <Wire.h>               // Arduino Wire (I2C) library included (v1.0)
                                // https://www.arduino.cc/reference/en/language/functions/communication/wire/

#include <LiquidCrystal_I2C.h>  // LiquidCrystal Arduino library for I2C PCF8574 based LCD displays (v1.1.2)
                                // https://github.com/johnrickman/LiquidCrystal_I2C/tree/1.1.2

// Instance an I2C LCD display (16 columns x 2 rows) at PCF8574 address 0x27
LiquidCrystal_I2C lcd(0x27, 16, 2);

// --------------------- Hardware configuration ---------------------

// Define buzzer and auto-off settings
#define BUZZER           16               // Arduino pin for active buzzer output: 16 / A2 (PortC, bit 2)
#define BEEP_TIME        50               // Default beep duration in milliseconds
#define WARNING_OFF     120               // Seconds to auto off warning beep (approximately because Timer0/millis() stops during measurements)
#define AUTO_OFF        180               // Seconds to auto off (approximately because Timer0/millis() stops during measurements)
#define MILLIS_S       1000UL             // Millis per second to fix Timer0/millis() stops during measurements

// Define ADC settings
#define ADC_U330U33       0               // ADC channel for measure U330 and U33 (not Arduino pin)
#define ADC_VBATT         1               // ADC channel for measure battery voltage (not Arduino pin)
#define ADC_VREF_TYPE     0               // Set to REFS0 (1 for internal Vcc or 0 for external VREF like 4.096v or similar)
#define ADC_VREF_VALUE    4.070           // Voltage of external VREF in volts, should be measured as accurately as possible.
#define ADC_CLOCK       0b110             // ADC prescaler (ADCSRA) to 64 (110) for 250Khz (@16Mhz)

// Define battery settings
#define VBATT_FACTOR      3.74            // Battery sense voltage divisor factor = 1 + ( R5 / R6 )
#define VBATT_MIN         6.0             // Minimum voltage for normal boot, or stop booting due to "low power"
#if ADC_VREF_TYPE == 1                    // Internal Vcc as VREF
  #define ADC_VREF_VALUE  5.0             // Assume 5.0v
#endif 
#define VBATT_MAX         VBATT_FACTOR*ADC_VREF_VALUE  // Max voltage that can be measured

// --------------------- Hardware based parameters ---------------------

// Factor for ESR range 1 Ohm using "U330 / M_ESR_1"
#define M_ESR_1          599.0                        // (float) ADC value (0 to 1023) using 1 ohm range (U330) minus "Set to Zero" user calibration for a 1 ohm reference resistor

// Factor for ESR range 10 Ohm using "U33 / M_ESR_10"
#define M_ESR_10          79.0                        // (float) ADC value (0 to 1023) using 10 ohms range (U33) by 10 for a 10 ohms reference resistor

// ESR range selector based on U330average threshold value
#define U330threshold     950U                        // (unsigned short integer) ADC value (0 to 1023) using 1 ohm range (U330), threshold to switch to use 10 ohms range (U33)

// Factor for calculate Cx using "Cx = ticks_counter / M_Cx"
#define M_Cx              51.0                       // (float) Number of Timer1 ticks per microfarad

// Internal correction for Cx Timer1 ticks counter
#define add_Cx            1000U                       // (unsigned short integer) Ticks = counter + ( USR_1_Cx - add_Cx ) // Default 1000 (no correction).

// ESR threshold to apply ESR compensation to Cx measure
#define ESRthreshold      2.5                         // (float) ESR value above which ESR compensation is applied to Cx measure

// U33 Comp timeout from timer1count
#define COMP_TIMEOUT      80U                         // (unsigned short integer) Number of Timer1 overflows. (80+1) * 65535 ticks per overflow = 5308335 ticks / M_Cx (ticks per microfarad) = 110360 uF max measure.
                                                      // Timer1 overflow every 4.0959375 msecs. (80+1) * 4.0959375 = 327ms. Increasing this parameter, the Cx max measure will be higher, but it will also be slower.
// Number of ACD measures
#define ACD_MEASURES      20U                         // (unsigned short integer) Number of ADC readings to average in each ESR calculation.

// CX IIR digital filter (Infinite Impulse Response)  // Exponential Moving Average (EMA meaning)
#define ALPHA_Cx          0.5                         // (float) Initial smoothing factor from 0 (full filter) to 1 (no filter)

// Cx IIR digital filter auto hold 
#define Cx_MEASURES       10U                         // (unsigned short integer) Number of Cx IIR digital filter measures until "auto-hold" (0 for no auto-hold)

// ESR limit
#define ESRlimit          1022.9/M_ESR_10             // (float) Max measurable ESR when ADC reading is close to 1023 using 10 ohms range (U33)

// --------------------- I/O port config ---------------------

// Set Port B configuration
#define Port_B_Config      0b00111111  // Manage outputs to Cx and gain selector
// Port B bit equates          ||||||
#define Cap_Charge      0 //   |||||·- PB0     Cap_Charge      Output      Original PIC RC0 - Cap charge when LOW "C" (via Q1 BJT PNP, 10mA limited by Z1 TL431 & R3 180R)
#define Cap_Discharge   1 //   ||||·-- PB1     Cap_Discharge   Output      Original PIC RC1 - Cap discharge when HIGH "D" (via Q2 N-Channel MOSFET IRF530N)
#define ADC_Gain_U330   2 //   |||·--- PB2     ADC_Gain_U330   Output      Select ADC gain "G" (0 (default) for U33, 1 for U330, via AD620 Rg) to CD4066B CMOS quad analog switch
#define In_N_Gnd        3 //   ||·---- PB3     In_N_Gnd        Output      Original PIC RC3 - GND "R" (remote control) to CD4066B CMOS quad analog switch
#define In_P_Cx         4 //   |·----- PB4     In_P_Cx         Output      Original PIC RC4 - CX  "+"                  to CD4066B CMOS quad analog switch
#define In_N_Cx         5 //   ·------ PB5     In_N_Cx         Output      Original PIC RC5 - CX  "-"                  to CD4066B CMOS quad analog switch (Arduino pin D13 builtin LED)

// Define Port B states        -+RGDC
#define ESR_ready          0b00110011   // Discharge, "+" and "-" Remote control on Cx
#define ESR_start          0b00110100   // Charge,    "+" and "-" Remote control on Cx, ADC gain "G" to U330
#define Cap_ready          0b00011011   // Discharge, "-" Remote control to ground, "+" to Cx
#define Cap_start          0b00011000   // Charge,    "-" Remote control to ground, "+" to Cx
#define Cap_start2         0b00110000   // Charge,    "-" Remote control on Cx,     "+" on Cx

// Set Port D configuration
#define Port_D_Config      0b10000000  // Manage inputs from LM393 comparator and user buttons
// Port D bit equates        ||||||||
//                      0    |||||||·- PD0        UART RX
//                      1    ||||||·-- PD1        UART TX
#define Comp_Up         2 // |||||·--- PD2/INT0   Comp_Up           Input       LOW when ADC (gain U33) > 2.0 v
#define Comp_Low        3 // ||||·---- PD3/INT1   Comp_Low          Input       LOW when ADC (gain U33) > 1.0 v
#define Menu_Button     4 // |||·----- PD4        Menu_Button       Input       "On/Off/Menu/Set" button pressed when LOW
#define Plus_Button     5 // ||·------ PD5        Plus_Button       Input       "(+) Plus" button pressed when LOW
#define Minus_Button    6 // |·------- RD6        Minus_Button      Input       "(-) Minus" button pressed when LOW
#define Power_Off       7 // ·-------- PD7        Power_Off         Output      Set to 1 for battery power or 0 for (auto) power off

// Inputs from external LM393 comparator
#define Comp_Up_HIGH    bit_is_set(PIND, Comp_Up)         // True while ADC (gain U33) < 2.0 v
#define Comp_Low_HIGH   bit_is_set(PIND, Comp_Low)        // True while ADC (gain U33) < 1.0 v

// Define input buttons
#define BUTTON_MENU     bit_is_clear(PIND, Menu_Button)   // True while button (MENU) is pressed
#define BUTTON_PLUS     bit_is_clear(PIND, Plus_Button)   // True while button (PLUS) is pressed
#define BUTTON_MINUS    bit_is_clear(PIND, Minus_Button)  // True while button (MINUS) is pressed

// Define Power ON/OFF
#define Set_Power_On    bitSet(PORTD, Power_Off)          // Set "Power On" status, keeping to HIGH the Power_Off output
#define Set_Power_Off   bitClear(PORTD, Power_Off)        // Set "Power Off" status, turn off battery power

// --------------------- LCD SYMBOLS ---------------------

#define SKIP  (byte)0                     // LCD custom char to skip address 0x00
#define OMEGA (byte)1                     // LCD custom char for Omega "Ω" character for Ohms
#define MU    (byte)2                     // LCD custom char for Mu "µ" character for prefix micro
#define BELL  (byte)3                     // LCD custom char for Bell character
#define LOCK  (byte)4                     // LCD custom char for Lock character

// LCD custom char at address 0x00, defined only to skip '\0'
byte skip[8] = {0};

// Omega "Ω" character for Ohms, better than LCD CGROM 0xF4 character
byte omega[8] = {
  0b00000000,0b00001110,0b00010001,0b00010001,0b00010001,0b00001010,0b00011011,0b00000000
};

// Mu "µ" character for prefix micro, better than LCD CGROM 0xE4 character
byte mu[8] = {
  0b00000000,0b00000000,0b00010010,0b00010010,0b00010010,0b00011110,0b00010001,0b00010000
};

// Bell character
byte bell[8] = {
  0b00000100,0b00001110,0b00001110,0b00001110,0b00011111,0b00000000,0b00000100,0b00000000
};

// Lock character
byte lock[8] = {
  0b00001110,0b00010001,0b00010001,0b00011111,0b00011011,0b00011011,0b00011111,0b00000000
};

// --------------------- EEPROM OFFSETS ---------------------

#define U0_ESR_1_EEPROM_OFFSET            0x00
#define U0_ESR_10_EEPROM_OFFSET           0x04
#define USR_1_EEPROM_OFFSET               0x08
#define USR_10_EEPROM_OFFSET              0x0C
#define USR_Cx_EEPROM_OFFSET              0x10
#define USR_1_Cx_EEPROM_OFFSET            0x14
#define ESR_METER_FLAG_EEPROM_OFFSET      0x18
constexpr const char ESR_METER_FLAG[] =   {'E','S','R','M','E','T','E','R'};

// Timeouts values
#define NO_TIMEOUT  0  // No timeout
#define TIMEOUT_CX0 1  // Cx_0 Wait until Cx is discharged
#define TIMEOUT_CX2 2  // Cx_2 Wait until U33 > 1.0v (Comp_Low)
#define TIMEOUT_CX3 3  // Cx_3 Wait until U33 > 2.0v (Comp_Up)
#define TIMEOUT_CX4 4  // User configuration for USR_1_Cx too low

// --------------------- Global vars ---------------------

uint8_t volatile timer1count_Cx2;         // Timer1 Cx2 overflow counter, volatile mandatory
uint8_t volatile timer1count_Cx3;         // Timer1 Cx3 overflow counter, volatile mandatory

uint16_t U330;                            // Raw ACD value for U330  (range 1 Ohm)
uint16_t U33;                             // Raw ACD value for U33  (range 10 Ohm)

float U330average         = 0;            // Average of ACD values for U330 (range 1 Ohm)
float U33average          = 0;            // Average of ACD values for U33 (range 10 Ohm)
uint32_t CxTicks;                         // Cx Timer1 total ticks (if not timeout)

uint32_t WarningOffTimer  = 0;            // Millis to auto-off warning beep (0 to disable)
uint32_t AutoOffTimer     = 0;            // Millis to auto-off (0 to disable)

bool ESR_RAW_VALUES       = false;        // Flag to clear raw values from second line

float CxAlpha             = ALPHA_Cx;     // Cx IIR digital filter's exponential smoothing factor
float CxFiltered          = 0;            // Filtered output value of Cx

// --------------------- EEPROM stored user calibration parameters ---------------------

// User correction for "Set to Zero" ESR range 1 Ohm using "ESR = (U330 - U0_ESR_1) / M_ESR_1"
uint16_t U0_ESR_1         = 0;            // Default 0 (no correction)

// User correction for "Set to Zero" ESR range 10 Ohms using "ESR = (U33 - U0_ESR_10) / M_ESR_10"
uint16_t U0_ESR_10        = 0;            // Default 0 (no correction)

// User correction factor for ESR range 1 Ohm using "ESR = ESR * USR_1"
float USR_1               = 1.000;        // Default 1.000 (no correction)

// User correction factor for ESR range 10 Ohm using "ESR = ESR * USR_10"
float USR_10              = 1.000;        // Default 1.000 (no correction)

// User correction factor for Cx "Cx = Cx * USR_Cx"
float USR_Cx              = 1.000;        // Default 1.000 (no correction)

// User correction for absolute value of Cx Timer1 ticks count using "counter + ( USR_1_Cx - add_Cx )"
uint16_t USR_1_Cx         = 1000;         // Default 1000 - add_Cx (1000) = 0 (no correction)
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
void loop() {

  // Checking for "On/Off/Menu/Set" button pressed to clear warning or power off or manual remeasure
  if (BUTTON_MENU and !BUTTON_MINUS and AutoOffTimer != 0) {

    // Clears Cx filtered measure  to force the Cx measurement to restart
    CxFiltered=0;

    // If after 150 ms the button is still pressed, the power off countdown begins.
    delay(150);
    if (BUTTON_MENU){
      beep(25);

      // Countdown to power off
      uint8_t  countdown    = 9;                          // From 9 to 0 total 10 steps 
      uint16_t pressedTime  = 3000;                       // Milliseconds that the button must be pressed
      uint16_t step         = pressedTime/10;
      uint32_t pressed      = millis() + pressedTime;

      // Long press (pressedTime ms) to power off
      while (BUTTON_MENU and (millis() < pressed)){

        // Countdown update check
        if (millis() > (pressed-pressedTime)){

          // Display countdown to upper right corner
          lcd.setCursor(15, 0);
          lcd.print(countdown);

          // Update countdown
          pressedTime = pressedTime-step;
          countdown--;

        }

        // Display "OFF" to lower right corner
        lcd.setCursor(13, 1);
        lcd.print(F("OFF"));
      }

      // If "On/Off/Menu/Set" button still pressed, then it "turns off"
      if (BUTTON_MENU) {

        beep(25);

        lcd.clear();
        lcd.setCursor(0, 1);
        lcd.print(F(" button release "));

        // Wait until the button is released
        while (BUTTON_MENU) {}

        // Power Off
        Set_Power_Off;

        // Wait to power off
        delay(100);

        // If still here it's because of USB power

        // Set "Power On", keeping to HIGH the POWER_OFF output (USB DEBUG) forces battery power if present
        Set_Power_On;

        // Beep warning
        beep(25);

        // Clear "button release" message
        lcd.clear();

        // Set max value to enable manual power-off
        AutoOffTimer = UINT32_MAX;

      } else {  // Sort press to clear warning

        // Clear "OFF" to lower right corner
        lcd.setCursor(13, 1);
        lcd.print(F("   "));

        // Clear countdown or bell char to upper right corner
        lcd.setCursor(15, 0);
        lcd.print(" ");

      }

      // Check for "lock" status
      if (AutoOffTimer == UINT32_MAX){
        // Re-display "lock char" to upper right corner
        lcd.setCursor(15, 0);        
        lcd.write(LOCK);
      }else{
        // Reset auto-off timers
        WarningOffTimer = millis() + (WARNING_OFF * MILLIS_S);
        AutoOffTimer = millis() + (AUTO_OFF * MILLIS_S);
      }
    }
  }

  // Checking for auto-off warning beep
  if ((WarningOffTimer > 0) and (millis() > WarningOffTimer)) {

    // Disable auto-off warning beep
    WarningOffTimer = 0;

    // Display "bell char" to upper right corner
    lcd.setCursor(15, 0);
    lcd.write(BELL);

    // Warning beep
    beep(100);
  }

  // Checking for auto-off
  if ((AutoOffTimer > 0) and (millis() > AutoOffTimer)) {

    // Disable auto-off
    AutoOffTimer = 0;

    // Power off beep
    beep(250);

    // Power Off
    Set_Power_Off;

    // Wait to power off
    delay(100);

    // If still here it's because of USB power

    // Set "Power On", keeping to HIGH the POWER_OFF output (USB DEBUG) forces battery power if present
    Set_Power_On;

    // Set max value to enable manual power-off
    AutoOffTimer = UINT32_MAX;

    // Display "lock char" to upper right corner
    lcd.setCursor(15, 0);
    lcd.write(LOCK);

  }

  // Display ESR on second line of LCD (normal or test mode)
  // Get ERS measure
  float esr = getESR();

  // Checking for (-) minus button pressed
  if (BUTTON_MINUS) {
    // Display raw U330 and U33 values "ESR test mode"
    display_ESR_raw(lcd);

    // Serial debug info for ESR measures
    Serial.print(F("ESR:"));Serial.print(esr,4);Serial.print(",");
    Serial.print(F("U330:"));Serial.print(U330);Serial.print(",");
    Serial.print(F("U33:"));Serial.print(U33);Serial.print(",");
    Serial.print(F("U330average:"));Serial.print(U330average);Serial.print(",");
    Serial.print(F("U33average:"));Serial.print(U33average);Serial.println();

    // Set flag to clear raw values from second line after
    if (not ESR_RAW_VALUES){
      ESR_RAW_VALUES = true;
    } 

    // Checking for "On/Off/Menu/Set" button pressed to "Set to Zero"
    if (BUTTON_MENU) {
      if ((U0_ESR_1 != U330) or (U0_ESR_10 != U33)) {
        // Set user correction for "Set to Zero" ESR range 1 Ohm (U330)
        U0_ESR_1 = U330;

        // Set user correction for "Set to Zero" ESR range 10 Ohm (U33)
        U0_ESR_10 = U33;

        // Save to EEPROM
        EEPROM.put(U0_ESR_1_EEPROM_OFFSET, U0_ESR_1);
        EEPROM.put(U0_ESR_10_EEPROM_OFFSET, U0_ESR_10);

        lcd.setCursor(0, 0);                // First line
        lcd.print(F("     Saved!    "));    // 15 chars
        delay(2000);
        lcd.setCursor(0, 0);                // First line
        lcd.print(F("               "));    // Clear 15 chars
      } else {
        lcd.setCursor(0, 0);                // First line
        lcd.print(F("      Done!    "));    // 15 chars
        delay(2000);
        lcd.setCursor(0, 0);                // First line
        lcd.print(F("               "));    // Clear 15 chars
      }
    }
  } else {

    // Clears ESR raw values if any
    if (ESR_RAW_VALUES){
      ESR_RAW_VALUES = false;
      lcd.setCursor(0, 1);                  // Second line
      lcd.print(F("                "));     // 16 chars
    }

    // Display ESR measure "normal run mode"
    display_ESR(lcd, esr);
  }

  // Display Cx on first line of LCD
  // If ESR < ESRlimit display Cx (normal or test mode)
  if (esr < ESRlimit) {

    // Delay to ensure Cx discharged
    delay(25);

    // Get calculated Cx measure
    float Cx = getCx(esr);

    if (Cx > 0) {
      // Apply IIR digital filter

      // Set initial value and exponential smoothing factor
      if ((CxFiltered > Cx*1.2) or (CxFiltered < Cx*(0.8))) {   // if Cx value difference > 20% from previous value, assume Cx as new measurement
        CxFiltered = Cx;
        CxAlpha=ALPHA_Cx;
      }else{
        if ((CxAlpha > 0.000) and (Cx_MEASURES > 0)){           // Stop adjusting after Cx_MEASURES measurements "auto-hold"
            CxAlpha = CxAlpha - float(ALPHA_Cx/Cx_MEASURES);
            if (CxAlpha <= 0.000){
              CxAlpha = 0;
              beep(5);                                          // "auto-hold" beep
            }
        }
      }

      // Get Exponential Moving Average as Cx filtered
      CxFiltered = (CxAlpha * Cx) + ((1 - CxAlpha) * CxFiltered);

    } else {
      // Force next Cx value as new measurement
      CxFiltered = 0;
    }

    // Checking for (+) plus button pressed
    if (BUTTON_PLUS) {
      // Display raw "Cx test mode"
      if (Cx > 0) {
        display_Cx_raw(lcd);                // First line
      } else {
        lcd.setCursor(0, 0);                // First line
        lcd.print(F(" Cx timeout "));       // 12 chars
        lcd.print(int(Cx * -1));            //  1 char
        lcd.print(F("  "));                 //  2 chars (3-1 chars padding)
      }

      // Serial debug info for raw Cx measures
      Serial.print(F("CxTicks:"));Serial.print(CxTicks);Serial.print(",");
      Serial.print(F("CxRaw:"));Serial.print(Cx,3);Serial.print(",");
      Serial.print(F("CxFiltered:"));Serial.print(CxFiltered,3);Serial.println();

    } else {
      // Display normal "Cx run mode"
      if (Cx > 0) {
        // If not timeout display Cx filtered measure
        display_Cx(lcd, CxFiltered);           // First line

      } else {
        // If timeout display "Auto" message
        lcd.setCursor(0, 0);                   // First line
        lcd.print(F(" Cx \x7E Auto \x7F   ")); // 15 chars (4-1 chars padding)
      }
    }
  } else {
  
    // Force next Cx value as new measurement
    CxFiltered = 0;

    // Skip Cx measure if ESR > ESRlimit
    lcd.setCursor(0, 0);                        // First line
    lcd.print(F(" Cx \x7E Skip \x7F   "));      // 15 chars (4-1 chars padding)
  }

  // Get battery voltage (Arduino Vin) or USB power
  float vbatt = adc_vbatt();

  // Check battery voltage
  if (vbatt < VBATT_MIN) { 

    beep(250);

    // Set LCD second line
    lcd.clear();
    lcd.setCursor(0, 1);

    // Display low battery warning
    lcd.print(F("Low power: "));  // 11 chars
    lcd.print(vbatt); //  "1.23"  //  4 chars
    lcd.print("v");               //  1 char

    // Debug battery info
    Serial.print(F("Low power: "));
    Serial.print(vbatt);
    Serial.println(F("v detected!"));
    
    delay(2000);

    // Power Off
    Set_Power_Off;
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

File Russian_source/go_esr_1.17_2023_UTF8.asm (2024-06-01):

;
;  Russian capacitance and ESR meter for electrolytic capacitors
;  Измеритель емкости и ESR электролитических конденсаторов (https://pro-radio.online/measure/3288/)
;      C/ESR meter (метр)
;
;  Autor (Автор)     Gints Oleg (Гинц Олег) http://www.rlc-esr.ru/index.php/ru/izmeritel-s-i-esr
;  Version (Версия)  1.01
;  Date (Дата)       20/04/2007
;
;  The program uses fragments of the FLC meter code (В программе использованы фрагменты кода измерителя FLC)
;  Alexander Buevsky, Minsk, Bielorrusia (Александра Буевского, г.Минск, Беларусь)
;  
;  Program update (Доработка программы) Misyuta Gennady (Мисюта Геннадий)
;  Version (Версия)  1.17
;  Date (Дата)       18/10/2019
;   - added battery charge indicator
;   - added correction constant for the minimum capacitance of the capacitor
;   - added ESR and Cx software filters for more stable display readings
;
; Microchip Assembler (MPASM) languaje, not MPLAB XC8 PIC Assembler (pic-as)
; Added english comments to mains sections by Jorge Rivera in June 2023
; See https://github.com/latchdevel/C_ESR_METER
;
; MICROCONTROLLER PIC16F876A OUTPUTS ASSIGNMENT (НАЗНАЧЕНИЕ ВЫВОДОВ КОНТРОЛЛЕРА PIC16F876A)
;*******************************************************************************************
; PIN  *  NAME                          * FUNCTION (НОГА * ИМЯ * НАЗНАЧЕНИЕ)
;*******************************************************************************************

;  1   *  MCLR/Vpp                      * Reset (Сброс)
;  2   *  RA0/AN0                       * ADC to measure U330 (выход ДУ) (Ку=330)
;  3   *  RA1/AN1                       * ADC to measure U33 (выход ДУ) (Ку=33)
;  4   *  RA2/AN2/Vref-                 * Button key Menu/Set Кн. Set coeff./Set "0"
;  5   *  RA3/AN3/Vref+                 * ADC to battery voltage monitoring (Контроль напряжения батареи) v1.17
;  6   *  RA4/T0CKI                     * Button key + (plus/test) Кн.+/Test
;  7   *  RA5/AN4/SS                    * Button key - (minus) Кн.-
;  8   *  Vss                           * GND
;  9   *  OSC1/CLKIN                    * Quartz 20 MHz (Кварц 20 МГц)
; 10   *  OSC2/CLKOUT                   * Quartz 20 MHz (Кварц 20 МГц)
; 11   *  RC0/T1OSO/T1CKI               * Charge Cx I=10mA (charge when LOW) (Заряд Сх)
; 12   *  RC1/T1OSI/CCP2                * Discharge Cx (Разряд Сх)
; 13   *  RC2/CCP1                      * Upper charging level comparator Cx (LOW if U33>2.0v) (Компаратор верхнего уровня зарядки Сх)
; 14   *  RC3/SCK/SCL                   * In_N_Gnd "-" to the ground "R" remote control (вх."-" на землю)
; 15   *  RC4/SDI/SDA                   * In_P_Cx "+" to Сх
; 16   *  RC5/SDO                       * In_N_Cx "-" to Сх
; 17   *  RC6/TX/CK                     * Lower charge level comparator Cx (LOW if U33>1.0v) (Компаратор нижнего уровня зарядки Сх)
; 18   *  RC7/RX/DT                     * Unused
; 19   *  Vss                           * +5V
; 20   *  Vdd                           * GND
; 21   *  RB0/INT                       * LCD_D4
; 22   *  RB1                           * LCD_D5
; 23   *  RB2                           * LCD_D6
; 24   *  RB3/PGM                       * LCD_D7
; 25   *  RB4                           * LCD_R/S
; 26   *  RB5                           * LCD_E
; 27   *  RB6/PGC                       * Unused
; 28   *  RB7/PGD                       * Unused

;****************************************************************************************

    list    p=PIC16F876a
    #include P16F876a.inc    ;20.000 MHz
    __CONFIG _CP_OFF & _BODEN_OFF & _HS_OSC & _WRT_OFF & _WDT_OFF & _PWRTE_ON & _DEBUG_OFF & _CPD_OFF & _LVP_OFF

Port_A_Config   equ b'11111111'         ;ADCs and button keys (all inputs)
;Port A bit equates     ||||||
;                       |||||·- RA0     ADC to measure U330
;                       ||||·-- RA1     ADC to measure U33
Kn_Set          equ 2;  |||·--- RA2     Button key Menu/Set
;                       ||·---- RA3     ADC to measure battery voltage (v1.17)
Kn_Plus         equ 4;  |·----- RA4     Button key + (plus/test)
Kn_Minus        equ 5;  ·------ RA5     Button key - (minus)

Port_B_Config   equ b'11000000'         ;Display LCD 16x2 (4-bit mode outputs)
;Port B bit equates   ||||||||
;                     |||||||·- RB0     LCD Data bit 4      
;                     ||||||·-- RB1     LCD Data bit 5
;                     |||||·--- RB2     LCD Data bit 6
;                     ||||·---- RB3     LCD Data bit 7
;                     |||·----- RB4     LCD Register Select (R/S)
LCD_E           equ 5;||·------ RB5     LCD Enable (E)
;                     |·------- RB6     (unused)
;                     ·-------- RB7     (unused)    

Port_C_Config   equ b'11000100'         ;Manage outpus to Cap and inputs from external LM393 comparator
;Port C bit equates   ||||||||
Cap_Charge      equ 0;|||||||·- RC0     Cap_Charge      Output      Cap charge when LOW "C"
Cap_Discharge   equ 1;||||||·-- RC1     Cap_Discharge   Output      Cap discharge when HIGH "D"
Comp_Up         equ 2;|||||·--- RC2     Comp_Up         Input       LOW if U33 > 2.0v
In_N_Gnd        equ 3;||||·---- RC3     In_N_Gnd        Output      RC3-GND- "R" (remote control)
In_P_Cx         equ 4;|||·----- RC4     In_P_Cx         Output      RC4-CX "+"
In_N_Cx         equ 5;||·------ RC5     In_N_Cx         Output      RC5-CX "-"
Comp_Low        equ 6;|·------- RC6     Comp_Low        Input       LOW if U33 > 1.0v
;                     ·-------- RC7     (unused)        Input       (unused) 

;Port C cap states      -+R DC
ESR_ready       equ b'00110011'         ;Discharge, "+" and "-" Remote control on Cx           (вкл. разряд, "+" и "-" ДУ на Cx)
ESR_start       equ b'00110000'         ;Charge,    "+" and "-" Remote control on Cx           (вкл. заряд, "+" и "-" ДУ на Cx)
Cap_ready       equ b'00011011'         ;Discharge, "-" Remote control to ground,  "+" to Cx   (вкл. разряд, "-" ДУ на землю, "+" на Cx)
Cap_start       equ b'00011000'         ;Charge,    "-" Remote control to ground,  "+" to Cx   (вкл. заряд, "-" ДУ на землю, "+" на Cx)
Cap_start2      equ b'00110000'         ;Charge,    "-" Remote control on Cx,      "+" on Cx   (вкл. заряд, "-" ДУ на Cx, "+" на Cx)

;Register bits flags (биты регистра)
TIMEOUT         equ 0                   ;for the allotted time, the measurements did not wait for the end of the charge
                                        ;за отведенное время измерения не дождались окончания заряда
INSIGZERO       equ 1                   ;leading zeros (незначащие нули)
POINT           equ 2                   ;decimal point (десятичная точка)
DISCHARGE       equ 3                   ;value check. digits when outputting (проверку знач. разрядов при выводе)
CHECK10OM       equ 4                   ;check 10 ohm (10 Ом)
SAVECONST       equ 5                   ;constant change flag (флаг изменения константы)
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

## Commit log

2024-06-01 Add 'Gerber' files
    [C_ESR_METER_107_R19 - CADCAM Bottom Copper.GBR, C_ESR_METER_107_R19 - CADCAM Bottom Silk Screen.GBR, C_ESR_METER_107_R19 - CADCAM Bottom Solder Resist.GBR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]
2024-06-01 Add BOM file
2024-06-01 Add C++ source code for Arduino Nano
2025-08-09 Update Gerber files to v1.0.8
    [C_ESR_METER_1.0.8_R11 - CADCAM Bottom Copper.GBR, C_ESR_METER_1.0.8_R11 - CADCAM Bottom Silk Screen.GBR, C_ESR_METER_1.0.8_R11 - CADCAM Bottom Solder Resist.GB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]
2025-08-09 Update BOM to v1.0.8
2025-10-05 Arduinization of code (#5)
    Refactored EEPROM handling for improved efficiency and clarity.
    Code now leverages native Arduino functionality for cleaner implementation.
    https://github.com/latchdevel/C_ESR_METER/issues/4
    [C_ESR_METER.ino]
2025-10-11 Refactor signed comparison (#7)
    Replaced negative literal "-1" with "UINT32_MAX" in both assignment and comparison involving AutoOffTimer, which is an unsigned type. This avoids implicit signed-to-unsigned promotion and improves clarity.
    Fixes issue #6 Intentional use of negative value to represent max unsigned
    [C_ESR_METER.ino]
2026-05-16 Update workflow for runner upgrade to Node24 (#9)
    Bumped actions/checkout and actions/upload-artifact to their latest versions to ensure compatibility with the Node24 runner.
    A temporary compatibility fix has been added while the official Arduino actions on GitHub are being updated. These actions, used in this workflow, are not yet compatible with Node24. This fix is a temporary solution to prevent workflow failures when GitHub changes the default runner to Node24 in June 2026.

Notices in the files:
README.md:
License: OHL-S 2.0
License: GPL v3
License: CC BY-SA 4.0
